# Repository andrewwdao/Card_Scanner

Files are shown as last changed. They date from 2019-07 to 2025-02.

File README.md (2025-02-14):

# Attendance Checking System for students of Can Tho University



 <!-- [![License](https://img.shields.io/github/license/minhan74/Card_Scanner.svg)](LICENSE) -->


## Download

```bash
git clone --recursive https://github.com/minhan74/Card_Scanner.git
git submodule update --init --recursive
```

## Documentation

This project aims to create a portable device that is used to check student attendance based on their student ID card.

* **[Full Report]**: detailed explaination on how we create this system and how to use it (school scientific research report - in Vietnamese).
* **[Hardware assembling instruction]**: how to re-create the hardware (extracted from the full report - in Vietnamese).
* **[Hardware files]**: ready-to-print parts of the cover and PCB.
* **[ESP32 - How to use the device]**: Guidance on how to properly setup the device for usage (extracted from the full report - in Vietnamese).
* **[ESP32 - Flash Instruction]**: Instruction on how to flash a ready-to-use binary file to esp32 (in English).
* **[ESP32 - Prepare Developing Environment]**: Guidance on how to prepare an appropriate developing environment for esp32 (in English).
* **[Web server - How to use]**: How to use the web server (in Vietnamese).
* **[Web server - Create localhost server]**: How to create a localhost server for locally use (in Vietnamese).
* **[Web server - Create globalhost server]**: How to create a globalhost server for internet use (in Vietnamese).

This project includes two main components:

* A Card Reader Device
* A Web Server

## Card Reader Device

This device is designed for reading student card, indicates student information and save these information into SD card. The device can connect to a server (locally or globally) to manipulate student's attendance information.

### Hardware

#### PCB

Designed in Altium 18.

Manufactured in china.

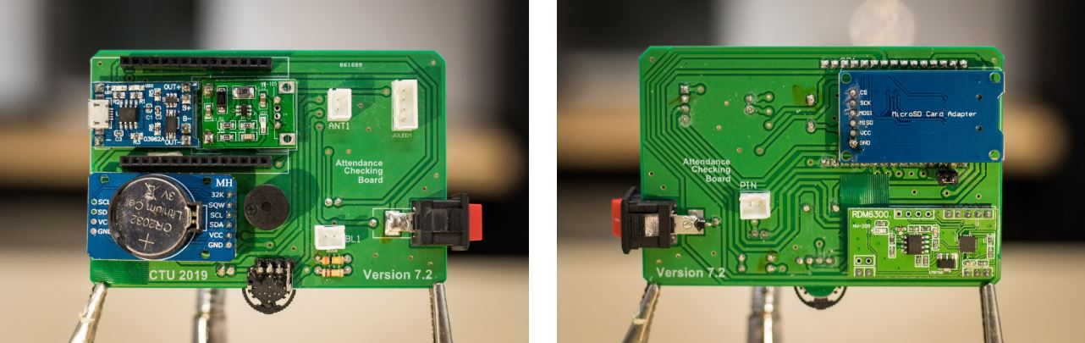
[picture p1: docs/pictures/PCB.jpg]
pcb


#### Cover

Designed using Fusion360.

Created by 3D printing and laser cutting.

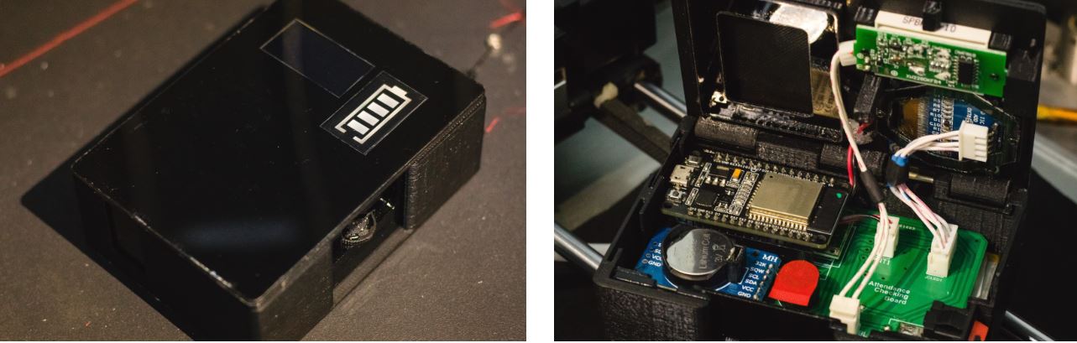
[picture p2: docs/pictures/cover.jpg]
cover


### Embedded software

Microcontroller: ESP32 DEV KIT V1

Peripherals: RDM6300 RFID reader, RTC module, SD card reader, 3-state button, voltage converter, lipo battery, lipo charger.

Run on both core of an ESP32 using FreeRTOS. Compiled by ESP-IDF with Arduino core as a component.

* ESP-IDF version: 3.2
* Compiler version: 5.2.0
* Arduino components version: 1.0.2

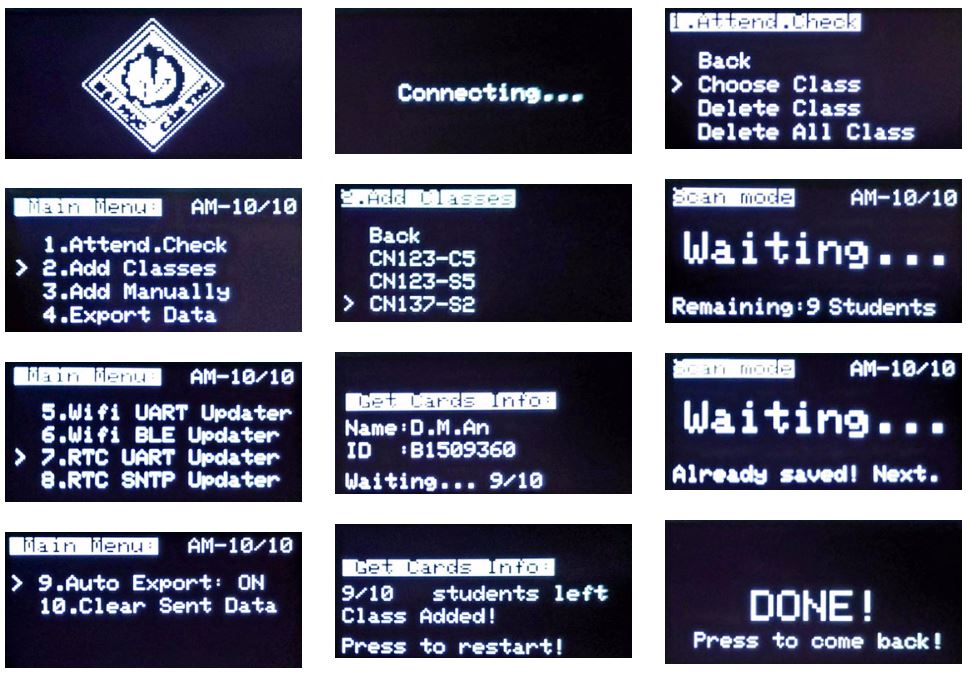
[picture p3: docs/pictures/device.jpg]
device


## Web Server

Written in PHP 7.3.18

Based on:

* Xampp v7.3.18
* Lavarel framework 5.6.22

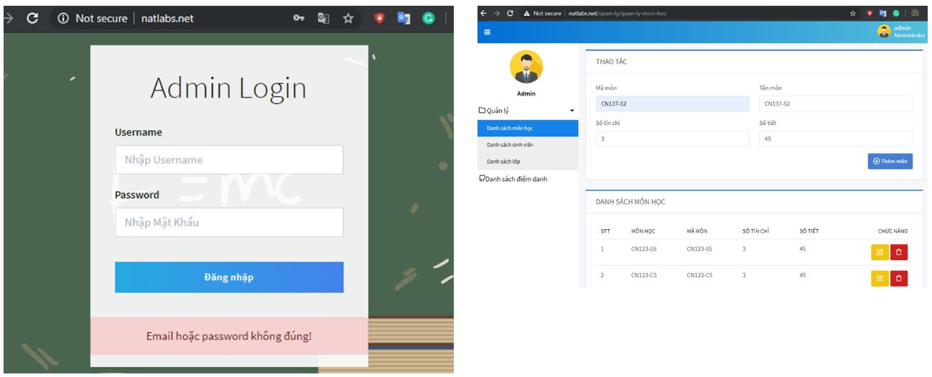
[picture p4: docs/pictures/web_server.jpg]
web_server


## Sponsor by

* Msc. Khac-Nguyen Nguyen, Can Tho University. <nknguyen@ctu.edu.vn>
* Can Tho University school scientific research fund.

## Supervised by

* Assoc. Prof. Chi-Ngon Nguyen, Can Tho University. <ncngon@ctu.edu.vn>
* Dr. Chanh-Nghiem Nguyen, Can Tho University. <ncnghiem@ctu.edu.vn>
* Msc. Khac-Nguyen Nguyen, Can Tho University. <nknguyen@ctu.edu.vn>

## Credited

* Mr. Quang-Thong Duong-Pham was responsible for PCB design, product testing and reporting.
* Mr. Quang-Nhut Tran was responsible for web server development.
* Mr. Anh-Khoi Tran was responsible for database and web server improving.
* Mr. Minh-An Dao was responsible for embedded software development.

 (c) 2019 Quang-Thong Duong-Pham <baronvn7197@gmail.com> - Quang-Nhut Tran <nhut1202@gmail.com> - Anh-Khoi Tran <khoitrananh.20@gmail.com> - Minh-An Dao <darns.smiths.9f@icloud.com> - Can Tho University.

<!-- Links -->
[Full Report]:https://bit.ly/card_scanner
[Hardware assembling instruction]:/docs/[Hardware]How_to_assemble.pdf
[Hardware files]: /hardware/
[ESP32 - How to use the device]:/docs/[ESP32]How_to_use_device.pdf
[ESP32 - Flash Instruction]: /docs/[ESP32]flash_ready-to-use_binary.md
[ESP32 - Prepare Developing Environment]: /docs/[ESP32]prepare_developing_environment.md
[Web server - How to use]: /docs/[Web_server]How_to_use_web_server.md
[Web server - Create localhost server]: /docs/[Web_server]Create_localhost_server.md
[Web server - Create globalhost server]:[Web_server]Create_globalhost_server.md

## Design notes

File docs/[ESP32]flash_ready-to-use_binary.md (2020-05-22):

# FLASH READY-TO-USE ESP32 BINARY (IN WINDOWS)

## Step 0: download [esptool]

You can skip this step if you already install the developing environment

## Step 1: Open mingw32.exe (if developing env is installed) or cmd (if install only esptool)

- Locate to the project folder (/esp32), you should see the file _CARD-SCANNER.bin_
- Plug in your esp32, determine the port name (COM5, COM14, ...)
- Download the binary file to the esp32:

```bash
python /<esptool directory>/esptool.py --chip esp32 --port COM14 --baud 921600 --before default_reset --after hard_reset write_flash -z --flash_mode dio --flash_freq 40m --flash_size detect 0x10000 /<project_directory>/CARD-SCANNER.bin
```

- Change the directory to your appropriate situation. Successfully uploaded program will look something like this:

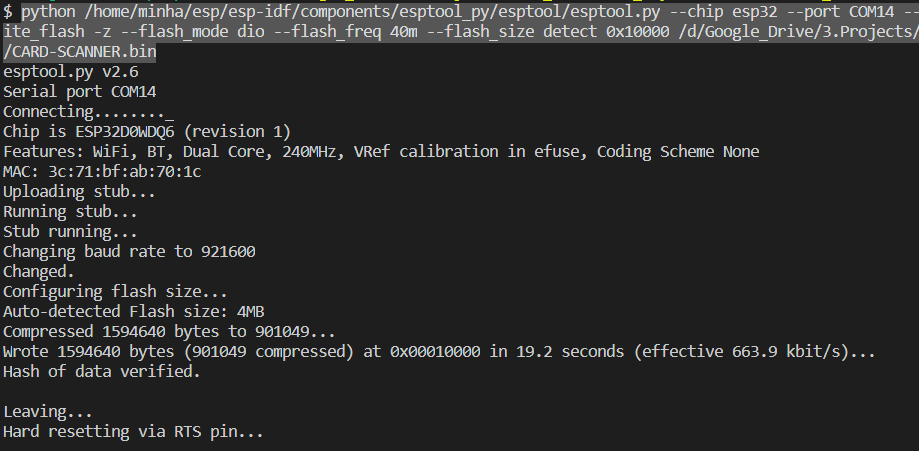
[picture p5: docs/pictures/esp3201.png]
esp3201
  

[esptool]: https://github.com/espressif/esptool

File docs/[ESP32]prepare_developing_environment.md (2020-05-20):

# PREPARE ESP-IDF PROGRAMMING ENVIRONMENT FOR ESP32

## Step 1: Download the environment – MSYS32

- Go to: <https://dl.espressif.com/dl/esp32_win32_msys2_environment_and_gcc8_toolchain-20191220.zip>
- Download the latest Windows all-in-one toolchain & MSYS2 zip file (~600mb)
- UNRAR the zip file in C:/
- Done setting up the pre-built environment.

## Step 2: Setting up the ESP-IDF framework

- Open mingw32.exe and start typing:

```bash
mkdir -p ~/esp
cd ~/esp
git clone --recursive https://github.com/espressif/esp-idf.git
```

- Add IDF_PATH to user profile:
  - Open the export_idf_path.sh in the crucial_files folder (within this folder) and fix the user to your user, then copy it to the directory: C:\msys32\etc\profile.d
  - Close MSYS2 window and reopen it and enter: printenv IDF_PATH to check the path
- Configure ESP-IDF to a useable version (old version, you can try to upgrade it later):

```bash
cd $IDF_PATH
git fetch
git checkout release/v3.2
git pull
git submodule update --init --recursive
python --version
python -m pip install --user -r $IDF_PATH/requirements.txt
```

## Step 3: Set up Arduino as a component in ESP-IDF

- Go to project folder, and type in

```bash
cd workspace/components/arduino
git checkout 1.0.2
git submodule update --init --recursive
```

- Replace _cc.h_ from crucial_files folder into _cc.h_ in:

```bash
C:\msys32\home\minha\esp\esp-idf\components\lwip\lwip\test\unit\esp\arch
```

This cc.h has been changed from:

```C
#include "ports/unix/port/include/arch/cc.h"
```

To

```C
#include "lwip/port/esp32/include/arch/cc.h"
```

## Step 4: open MSYS2 (mingw32.exe) and move to project folder (/esp32/workspace/)

- Try to compile source code with

```bash
make clean
make -j4 app
```

- Final message should be like this:

esp3202

- If the above message appears, then congratulation, you are properly set up esp-idf environment for this project.
- However, this environment is out dated. If you need to upgrade to the latest release, please make backup where needed since it will need a lot of careful modification to successfully compile with newer version.

**You can now use VScode or your favorite text editor to edit the code.**

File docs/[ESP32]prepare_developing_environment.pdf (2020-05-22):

# PREPARE ESP-IDF PROGRAMMING ENVIRONMENT FOR ESP32

## Step 1: Download the environment – MSYS32

Go to: https://dl.espressif.com/dl/esp32_win32_msys2_environment_and_gcc8_toolchain-20191220.zip Download the latest Windows all-in-one toolchain & MSYS2 zip file (~600mb)
UNRAR the zip file in C:/
Done setting up the pre-built environment.

## Step 2: Setting up the ESP-IDF framework

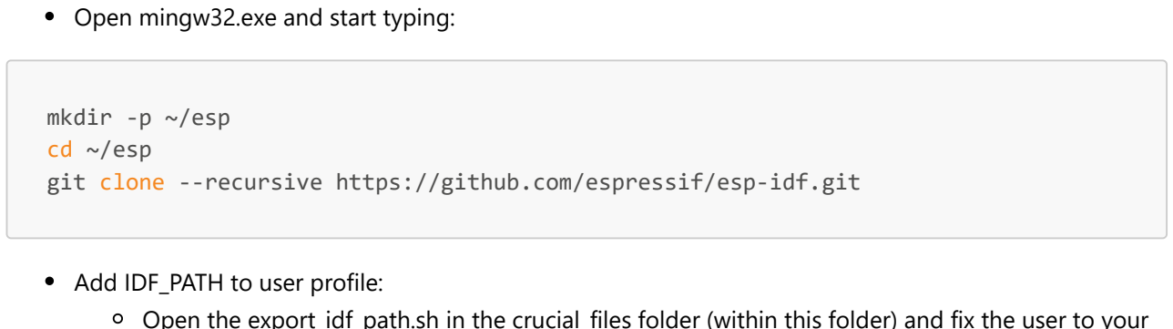
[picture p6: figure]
Open mingw32.exe and start typing:; mkdir -p ~/esp cd ~/esp git clone --recursive https://github.com/espressif/esp-idf.git; Add IDF_PATH to user profile:

Open the export_idf_path.sh in the crucial_files folder (within this folder) and fix the user to your user, then copy it to the directory: C:\msys32\etc\profile.d
Close MSYS2 window and reopen it and enter: printenv IDF_PATH to check the path
Configure ESP-IDF to a useable version (old version, you can try to upgrade it later):

cd $IDF_PATH
git fetch
git checkout release/v3.2
git pull
git submodule update --init --recursive
python --version
python -m pip install --user -r $IDF_PATH/requirements.txt

## Step 3: Set up Arduino as a component in ESP-IDF

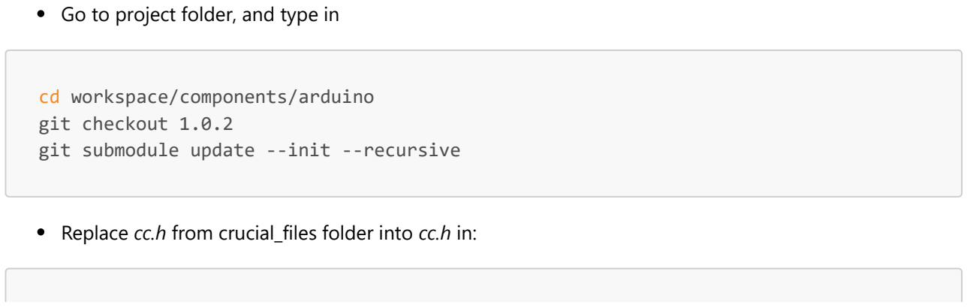
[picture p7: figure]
Go to project folder, and type in; cd workspace/components/arduino git checkout 1.0.2 git submodule update --init --recursive

Replace cc.h from crucial_files folder into cc.h in:

C:\msys32\home\minha\esp\esp-idf\components\lwip\lwip\test\unit\esp\arch

This cc.h has been changed from:

#include "ports/unix/port/include/arch/cc.h"

To

#include "lwip/port/esp32/include/arch/cc.h"

## Step 4: open MSYS2 (mingw32.exe) and move to project folder (/esp32/workspace/)

Try to compile source code with

make clean
make -j4 app

Final message should be like this:

If the above message appears, then congratulation, you are properly set up esp-idf environment for this project.
However, this environment is out dated. If you need to upgrade to the latest release, please make backup where needed since it will need a lot of careful modification to successfully compile with newer version.

You can now use VScode or your favorite text editor to edit the code.

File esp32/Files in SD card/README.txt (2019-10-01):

***Follow this instruction to properly use the Attendance Checking Device

Folder:
- Await:  this folder will store data files that haven't transfer to the server
- Sent:   this folder will store data files that have been transfer successfully to the server
- Import: this folder will help you import data manually to the system (see README.txt inside this folder)

This content is created by CTU students
(c) 2019 - An Minh Dao - Nhut Quang Tran - Thong Pham Quang Duong

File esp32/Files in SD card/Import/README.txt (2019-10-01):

*Copy your files to this folder to manually import data to the System
***Instruction: 

*Step 1:
First, save the class name into the file "classes.txt" in this folder.
For example, you want to import class CN123-S6.
 - Open "classes.txt"
 - Add: CN123-S6 to a new line
 - Press enter to confirm
 - Save the file and exit

*Step 2:
Prepare your class file as followed:
 - Class file name: 
CN123-S6.txt
 - Content:
B1509360|Dao Minh An
B1509361|Pham Hoang Anh
B1509397|Tran Quang Nhut
B1509399|Le Vo Thanh Phong
B1509482|Duong Pham Quang Thong

 - Press enter to confirm
 - Save the file to this folder

*Step 3:
Eject the SD card, put it on the Device, choose Import Manually

Enjoy.

This content is created by CTU students
(c) 2019 - An Minh Dao - Nhut Quang Tran - Thong Pham Quang Duong

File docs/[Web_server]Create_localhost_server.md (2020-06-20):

# HƯỚNG DẪN TẠO SERVER LOCAL

- Để chạy localhost, ta cần cài đặt:

[Xampp v7.3.18 x64](https://www.apachefriends.org/xampp-files/7.3.18/xampp-windows-x64-7.3.18-0-VC15-installer.exe)
[Xampp v7.3.2 x32](https://sourceforge.net/projects/xampp/files/XAMPP%20Windows/7.3.2/xampp-portable-win32-7.3.2-0-VC15-installer.exe/download)

- **Bước 0:** Đưa php vào system path:

  - Nhấn phím windows, nhập “path” để tìm Edit the system environment variable:

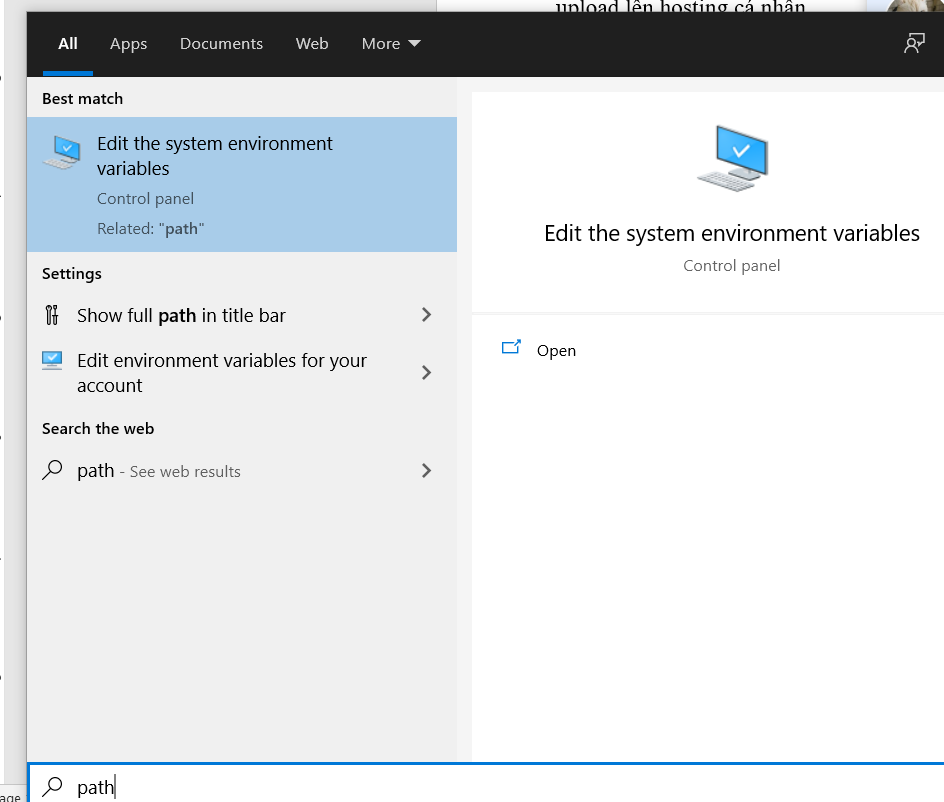
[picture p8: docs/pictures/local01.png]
local01
  

  - Chọn Environment Variables:

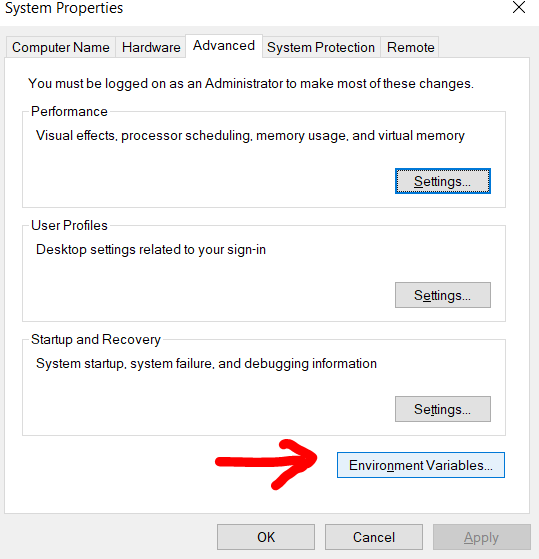
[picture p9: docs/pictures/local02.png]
local02
  

  - Chọn path > Edit:

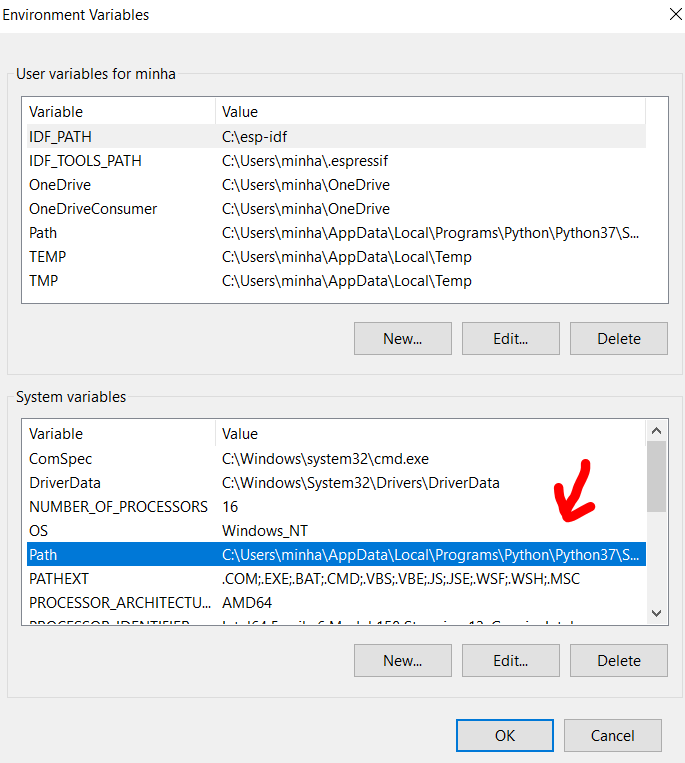
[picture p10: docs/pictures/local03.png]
local03
  

  - Chọn New, điền vào C:\xampp\php

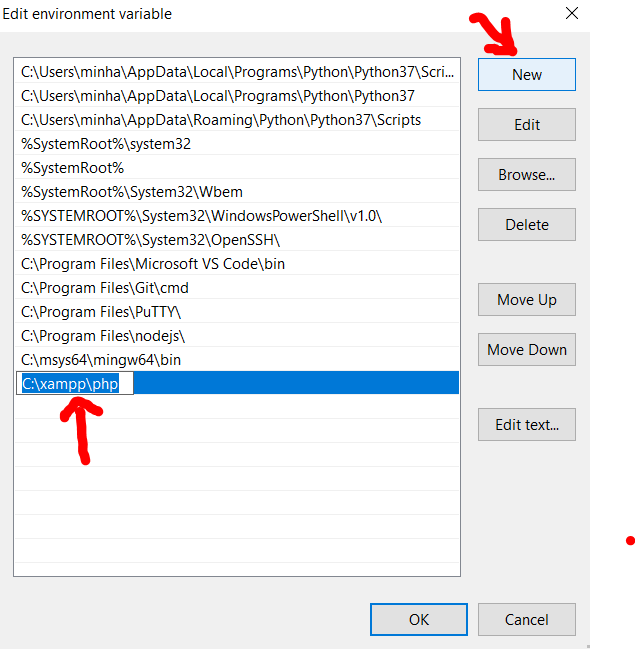
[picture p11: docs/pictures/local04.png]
local04
  

  - Chọn OK để save lại.

- **Bước 1:** Giải nén file card_scanner.zip(\web_server\local\) và chép thư mục card_scanner vào thư mục C:\xampp\htdocs.
- **Bước 2:** Khởi động phần mềm Xampp để tạo môi trường cho Localhost. Nhấn Start cho Apache và MySQL.

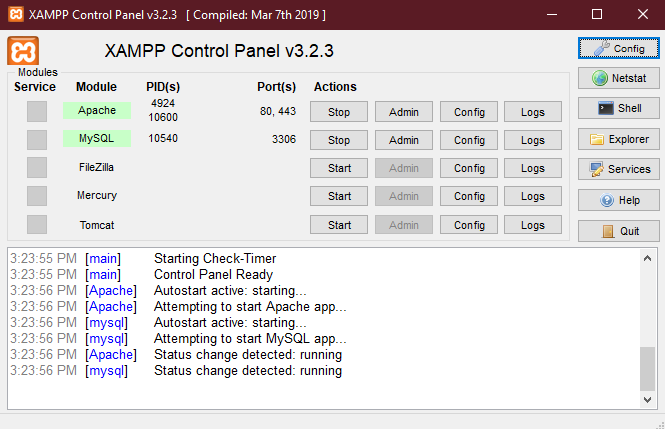
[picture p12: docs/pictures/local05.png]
local05


- **Bước 3:** truy cập <http://localhost/phpmyadmin> để vào trang quản lý Database.
  - Tạo new database với tên countstd:

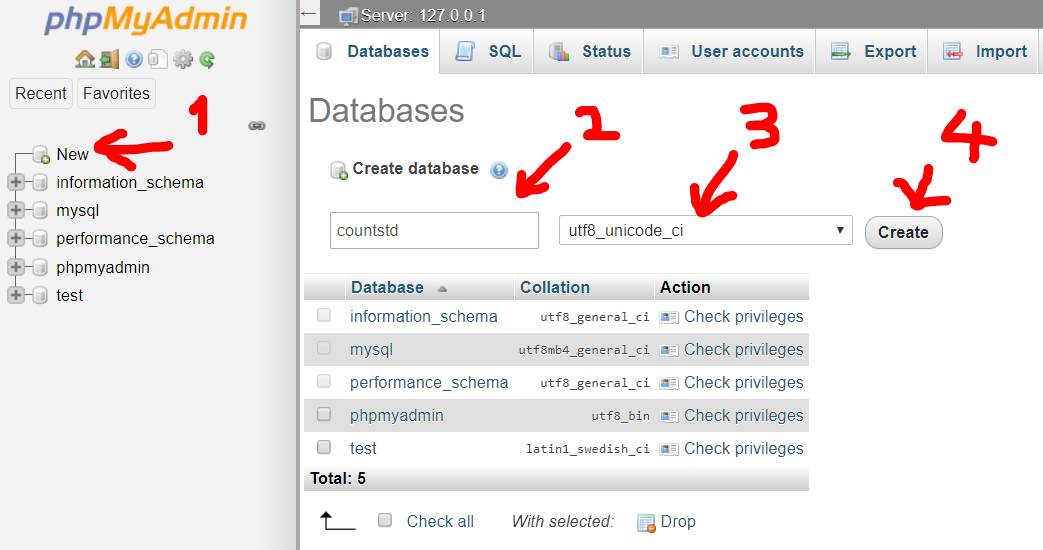
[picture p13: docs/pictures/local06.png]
local06
  

  - Import database có sẵn vào database vừa được tạo, chọn import:

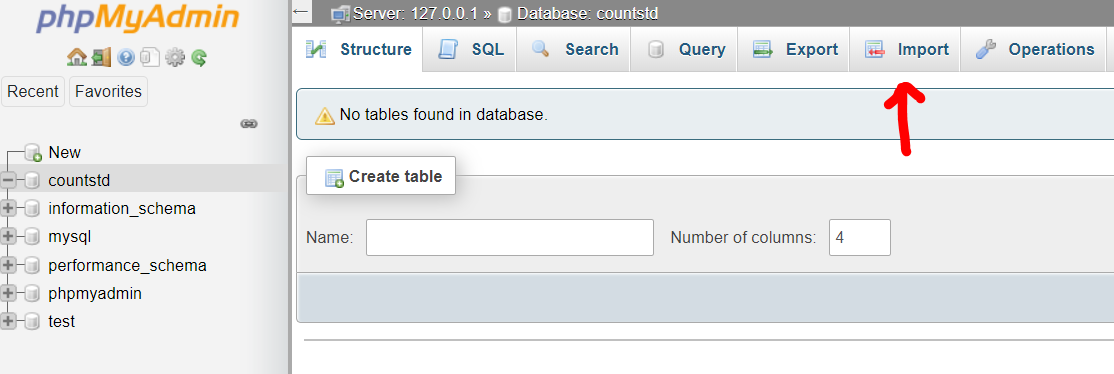
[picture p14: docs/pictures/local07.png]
local07
  

  - Chọn Choose file và chọn vào file countstd.sql (\web_server\local\) > Bấm Go ở cuối trang

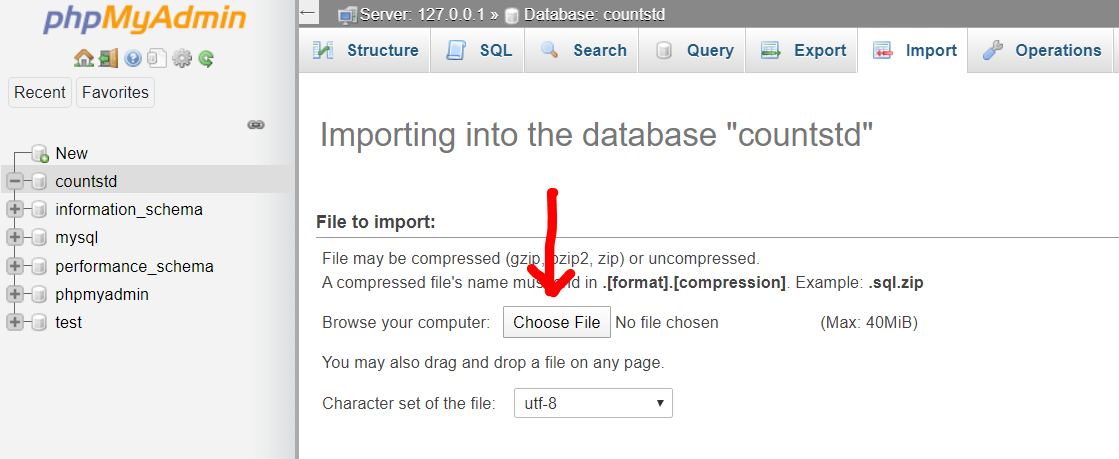
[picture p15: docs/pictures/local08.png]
local08
  

- **Bước 4:** Mặc định, hệ thống đã có tài khoản admin. Nếu muốn thay đổi tài khoản admin, xóa admin cũ trong bảng admin từ database countstd trong phpMyAdmin, sau đó truy cập vào tệp tin _DatabaseSeeder.php_ theo đường dẫn C:\xampp\htdocs\card_scanner\database\seeds. Thay đổi thông tin tài khoản đăng nhập mong muốn:

```python
class seedAdmin extends Seeder
{
    public function run()
    {
        DB::table('admin')->insert([
            ['taikhoan' => 'tên đăng nhập ở đây', 'password' => bcrypt('Mật khẩu ở đây')],
            ['taikhoan' => 'admin', 'password' => bcrypt('123456')],
        ]);
    }
}
```

- **Bước 5:** Mở cmd, gõ vào:

```bash
cd C:\xampp\htdocs\card_scanner
```

- **Bước 6:** Thực thi thay đổi cơ sở dữ liệu (LƯU Ý: nếu gặp lỗi, thì kiểm tra lại bảng admin từ database và đảm bảo không có tài khoản admin bị trùng):

```bash
php artisan db:seed
```

- **Bước 7:** Tiến hành chạy server:

```bash
php artisan serve --port=2020
```

local09

- **Bước 8:** Truy cập _<http://localhost:2020>_ hoặc nhấp đúp vào shortcut _Card Scanner Web Server_ (C:\xampp\htdocs\card_scanner) để truy cập hệ thống.

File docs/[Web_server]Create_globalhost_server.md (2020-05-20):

# HƯỚNG DẪN UPLOAD SOURCE CODE LÊN HOSTING CÁ NHÂN

- Hiện tại mã nguồn của hệ thống quản lý điểm danh đang được quản lý dưới tên tài khoản mặc định được tạo sẵn như sau:
  - Username: admin
  - Password: 123456
- Để bắt đầu upload source code lên hosting cá nhân trước hết phải đảm bảo người dùng đã có đủ 2 yếu tố là:
  - Hosting: là máy chủ sẽ chứa toàn bộ mã nguồn và đảm bảo đáp ứng kết nối từ phía người dùng. Ở hướng dẫn này sẽ dử dụng hosting là hawkhost.com. Đối với hosting cần có MySQL Databases.
  - Domain: là tên miền cho phép truy cập vào hệ thống máy chủ. Tên miền sử dụng trong hướng dẫn này là www.natlabs.net
- Khi đã có đủ các điều kiện cần thiết ta sẽ tiến hành upload theo các bước sau:
  - Đăng nhập vào cPanel của hosting bằng cách nhập url vào trình duyệt web với cú pháp: www.“your-domain”/cpanel. (VD: www.natlabs.net/cpanel )
  - Trình duyệt sẽ điều hướng đến trang đăng nhập như sau:

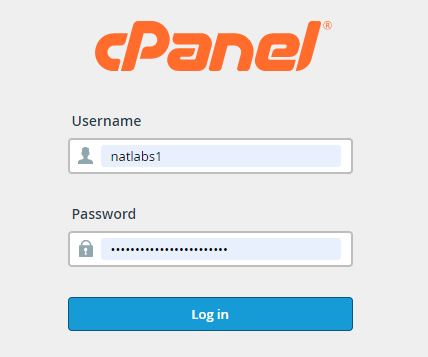
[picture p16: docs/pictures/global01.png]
Global01
  

  - Sau khi đăng nhập thành công ta chọn File Manager để truy cập vào trình quản lý tệp tin của máy chủ như sau:
  
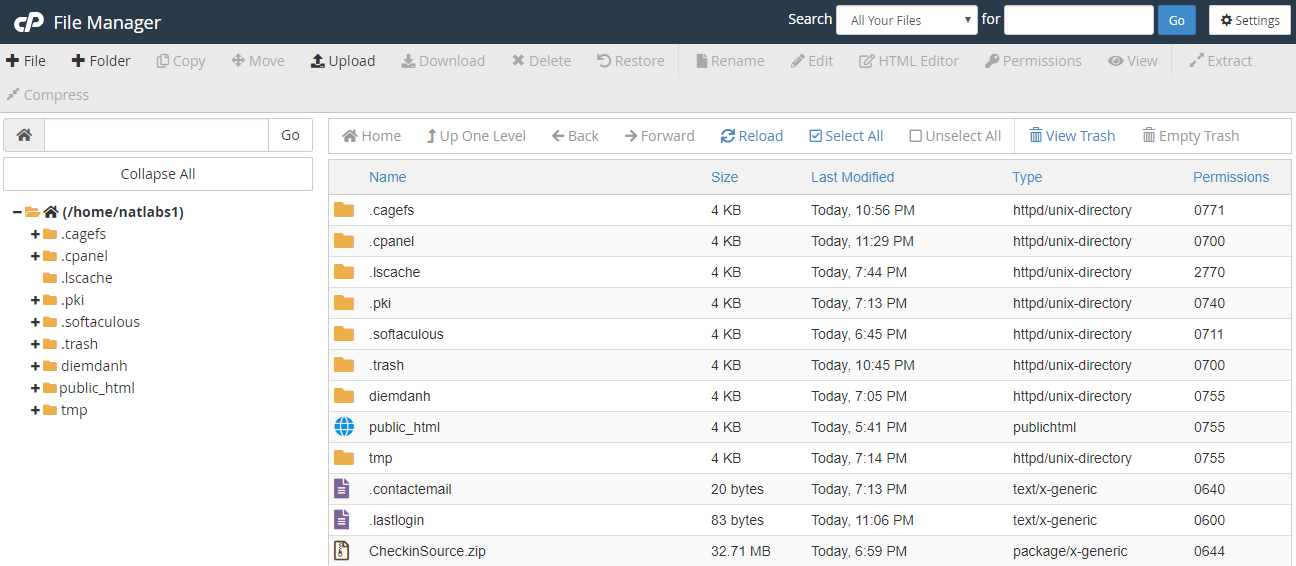
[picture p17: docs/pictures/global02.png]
Global02
  

  - Ở giao diện File Manager ta nhấp chuột chọn nút Upload trên thanh công cụ, sau đó nhấp chọn nút Upload File và trỏ đến thư mục chưa tệp tin CheckinSource.zip (\web_server\global\) và bấm Open. Sau đó chờ tệp tin được upload thành công vào hệ thống.
  - Quay lại giao diện File Manager nhấp chuột phải vào tệp tin CheckinSource.zip chọn Extract và chờ đến khi tệp tin được xả nén thành công. Ta sẽ thấy lúc này sẽ xuất hiện 2 thư mục mới có tên là “card_scanner” và “publish_html”.
  
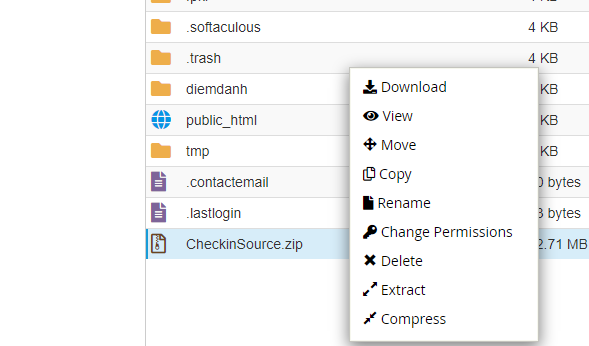
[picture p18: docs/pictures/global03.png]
Global03
  

  - Như vậy là đã thành công upload sources code lên hệ thống cPanel của hosting.
- Quay lại giao diện chính của cPanel chọn MySQL Databases trong mục Database. Trình duyệt sẽ điều hướng đến trang quản lý cơ sở dữ liệu.
  - Ta tạo 1 cơ sở dữ liệu mới tên “countstd” như hình và nhấp chuột vào nút Create Database.
  
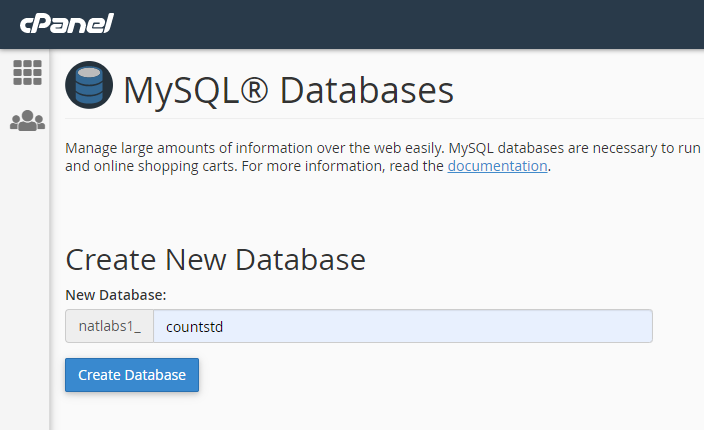
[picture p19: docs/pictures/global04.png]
Global04
  

  - Tiếp tục tạo User Database như hình bên dưới và nhấp nút Create User
  
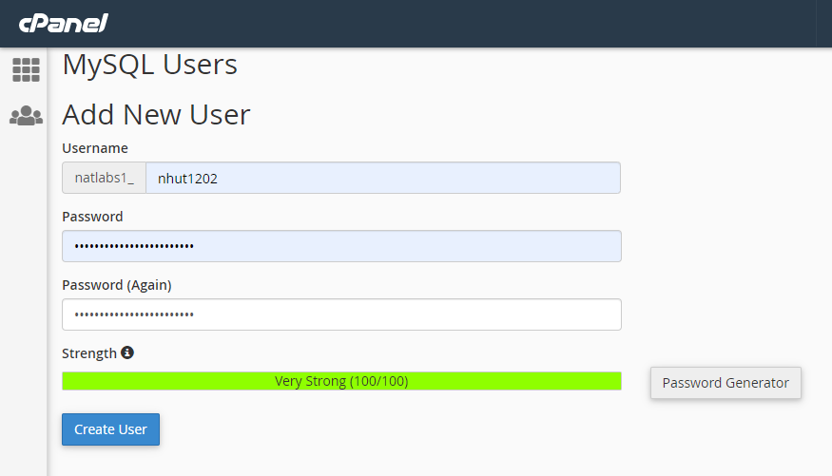
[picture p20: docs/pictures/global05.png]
Global05
  

  - Tiếp tục là liên kết User vừa tạo với Database đã tạo ở trên bằng cách chọn và nhấp chuột vào nút Add như hình:
  
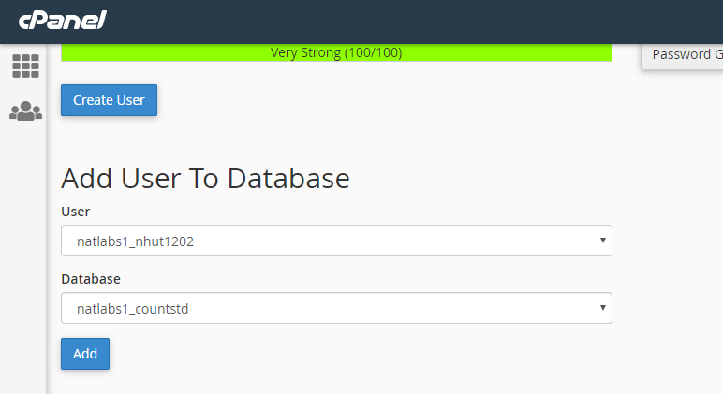
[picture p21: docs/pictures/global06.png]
Global06
  

- Sau khi đã hoàn tất các bước tạo cơ sở dữ liệu, ta quay lại giao diện File Manager nhấp chuột truy cập vào thư mục “card_scanner”.
  - Nhấp chọn nút Setting ở góc trên bên trái của giao diện File Manager. Trong hộp thoại “Freferences”, tích chọn Show Hidden File sau đó nhấp chọn Save để lưu và đóng hộp thoại.
  
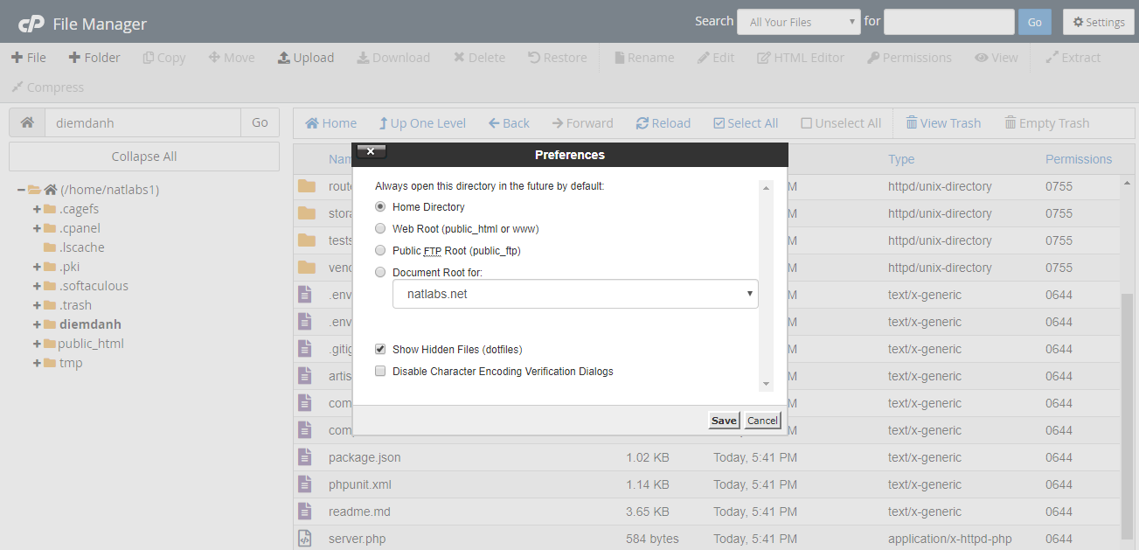
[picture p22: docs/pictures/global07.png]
Global07
  

  - Trong thư mục “card_scanner” ta nhấp chọn chuột phải vào tệp tin .env và chọn Edit
  
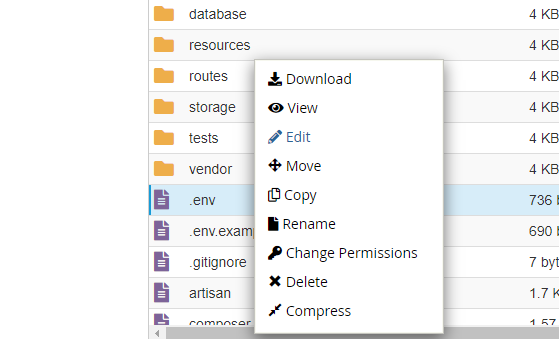
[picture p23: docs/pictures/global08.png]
Global08
  

  - Trong trang Edit tệp tin .env ta sửa lại các thông số liên quan đến Database ở dòng 12, 13, 14 lần lượt là Tên DB, User và Password vừa tạo ở trên. Sau đó nhấp chọn nút Save Change để lưu thay đổi.
  
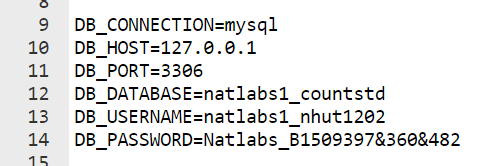
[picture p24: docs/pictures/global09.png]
Global09
  

- Quay lại giao diện chính của cPanel chọn mục phpMyAdmin.
  - Trong giao diện phpMyAdmin chọn tên Database đã tạo ở danh sách DB phía bên trái, sau đó nhấp chọn nút Insert. Trong mục File to import nhấp chọn nút Choose File và trỏ đến file “countstd.sql” trên máy tính và nhấp chọn Open.
  
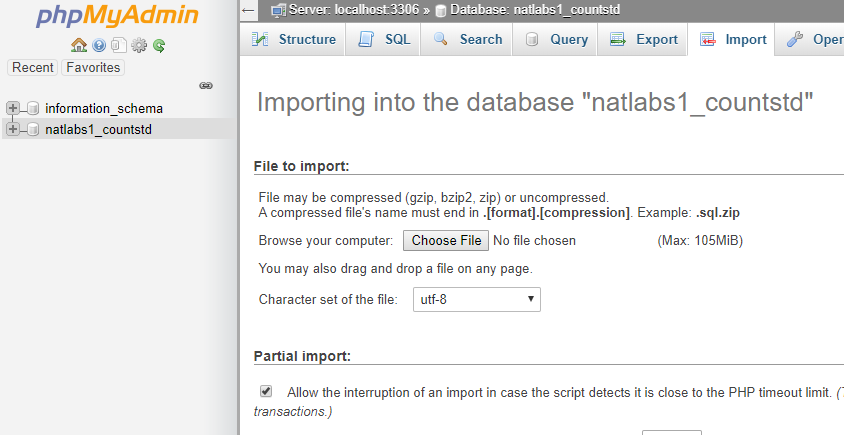
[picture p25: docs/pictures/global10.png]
Global10
  

  - Lăn cuộn chuột đến cuối trang và nhấp chọn nút Go để import cơ sở dữ liệu vào MySQL.
- Lúc này ta truy cập vào Domain đã đăng ký để truy cập vào trang đăng nhập của hệ thống điểm danh với tài khoản mặc định ở trên.
- Vậy là ta đã hoàn thành việc publish source code của hệ thống điểm danh lên hosting cá nhân thành công. Hệ thống server điểm danh đã sẵn sàng để sử dụng.

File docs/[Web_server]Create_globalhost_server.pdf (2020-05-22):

# HƯỚNG DẪN UPLOAD SOURCE CODE LÊN HOSTING CÁ NHÂN

Hiện tại mã nguồn của hệ thống quản lý điểm danh đang được quản lý dưới tên tài khoản mặc định được tạo sẵn như sau:

Username: admin
Password: 123456

Để bắt đầu upload source code lên hosting cá nhân trước hết phải đảm bảo người dùng đã có đủ 2 yếu tố là:

Hosting: là máy chủ sẽ chứa toàn bộ mã nguồn và đảm bảo đáp ứng kết nối từ phía người dùng. Ở hướng dẫn này sẽ dử dụng hosting là hawkhost.com. Đối với hosting cần có MySQL Databases.
Domain: là tên miền cho phép truy cập vào hệ thống máy chủ. Tên miền sử dụng trong hướng dẫn này là www.natlabs.net

Khi đã có đủ các điều kiện cần thiết ta sẽ tiến hành upload theo các bước sau:

Đăng nhập vào cPanel của hosting bằng cách nhập url vào trình duyệt web với cú pháp: www.“your-domain”/cpanel. (VD: www.natlabs.net/cpanel )
Trình duyệt sẽ điều hướng đến trang đăng nhập như sau:

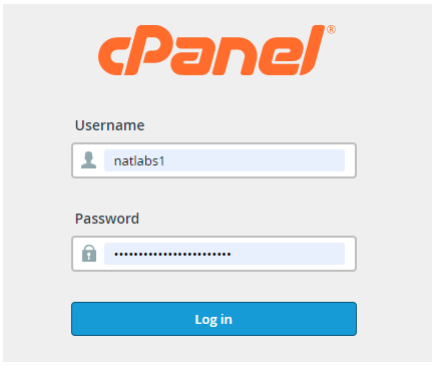
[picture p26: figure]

Sau khi đăng nhập thành công ta chọn File Manager để truy cập vào trình quản lý tệp tin của máy chủ như sau:


Ở giao diện File Manager ta nhấp chuột chọn nút Upload trên thanh công cụ, sau đó nhấp chọn nút Upload File và trỏ đến thư mục chưa tệp tin CheckinSource.zip (\web_server\global) và bấm Open. Sau đó chờ tệp tin được upload thành công vào hệ thống.
Quay lại giao diện File Manager nhấp chuột phải vào tệp tin CheckinSource.zip chọn Extract và chờ đến khi tệp tin được xả nén thành công. Ta sẽ thấy lúc này sẽ xuất hiện 2 thư mục mới có tên là “card_scanner” và “publish_html”.

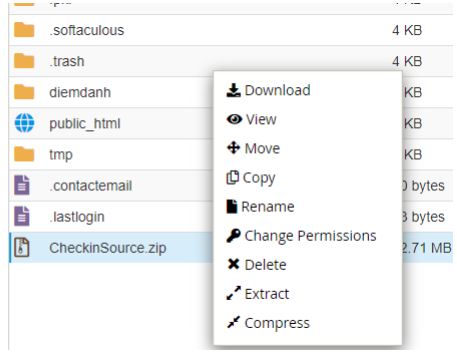
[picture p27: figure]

Như vậy là đã thành công upload sources code lên hệ thống cPanel của hosting.

Quay lại giao diện chính của cPanel chọn MySQL Databases trong mục Database. Trình duyệt sẽ điều hướng đến trang quản lý cơ sở dữ liệu.

Ta tạo 1 cơ sở dữ liệu mới tên “countstd” như hình và nhấp chuột vào nút Create Database.

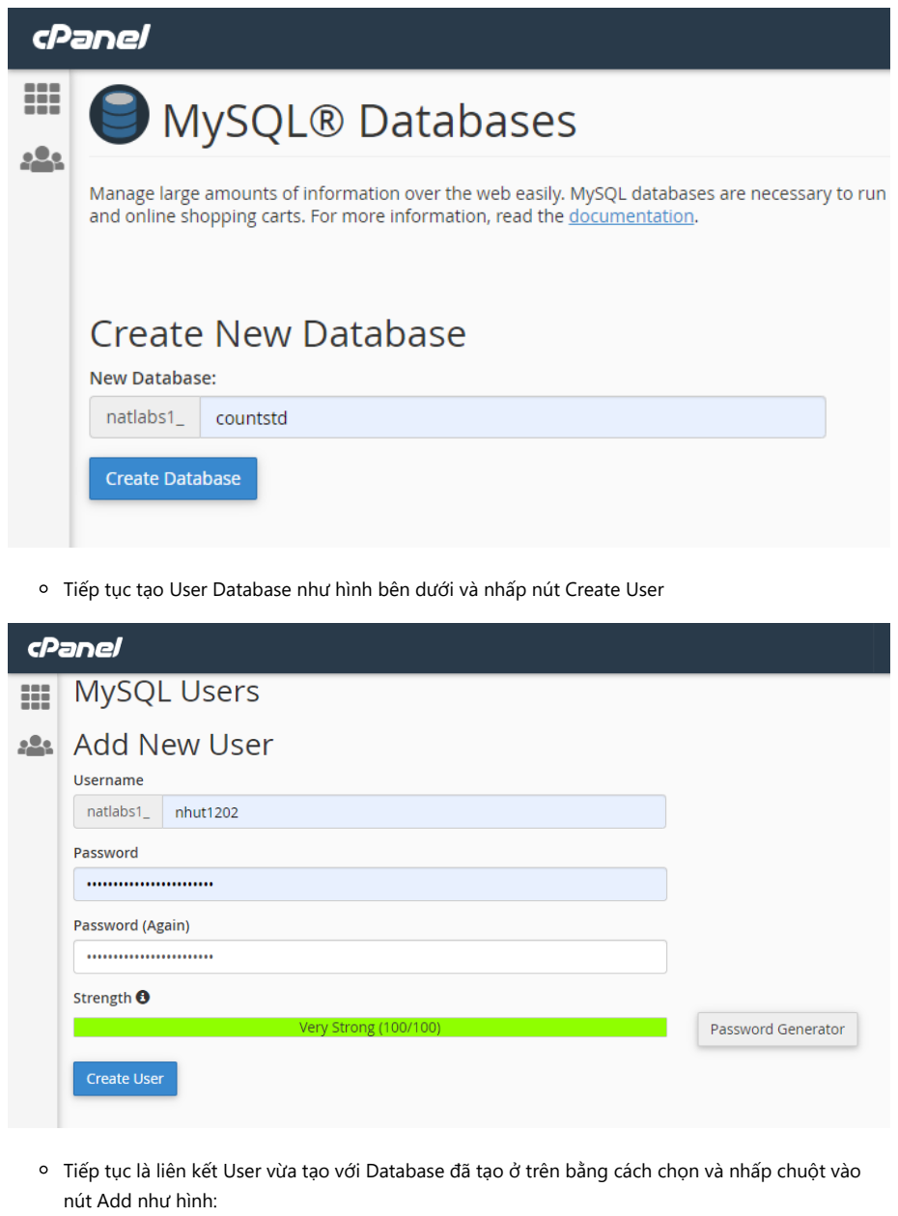
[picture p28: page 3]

Tiếp tục tạo User Database như hình bên dưới và nhấp nút Create User

Tiếp tục là liên kết User vừa tạo với Database đã tạo ở trên bằng cách chọn và nhấp chuột vào nút Add như hình:


Sau khi đã hoàn tất các bước tạo cơ sở dữ liệu, ta quay lại giao diện File Manager nhấp chuột truy cập vào thư mục “card_scanner”.

Nhấp chọn nút Setting ở góc trên bên trái của giao diện File Manager. Trong hộp thoại “Freferences”, tích chọn Show Hidden File sau đó nhấp chọn Save để lưu và đóng hộp thoại.

Trong thư mục “card_scanner” ta nhấp chọn chuột phải vào tệp tin .env và chọn Edit


Trong trang Edit tệp tin .env ta sửa lại các thông số liên quan đến Database ở dòng 12, 13, 14 lần lượt là Tên DB, User và Password vừa tạo ở trên. Sau đó nhấp chọn nút Save Change để lưu thay đổi.

Quay lại giao diện chính của cPanel chọn mục phpMyAdmin.

Trong giao diện phpMyAdmin chọn tên Database đã tạo ở danh sách DB phía bên trái, sau đó nhấp chọn nút Insert. Trong mục File to import nhấp chọn nút Choose File và trỏ đến file “countstd.sql” trên máy tính và nhấp chọn Open.

với tài khoản mặc định ở trên.

Lăn cuộn chuột đến cuối trang và nhấp chọn nút Go để import cơ sở dữ liệu vào MySQL.

Lúc này ta truy cập vào Domain đã đăng ký để truy cập vào trang đăng nhập của hệ thống điểm danh

Vậy là ta đã hoàn thành việc publish source code của hệ thống điểm danh lên hosting cá nhân thành công. Hệ thống server điểm danh đã sẵn sàng để sử dụng.

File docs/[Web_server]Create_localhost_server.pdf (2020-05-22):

# HƯỚNG DẪN TẠO SERVER LOCAL

Để chạy localhost, ta cần cài đặt:

Xampp v7.3.18 (https://www.apachefriends.org/xampp-files/7.3.18/xampp-windows-x64-7.3.18-0-VC15-installer.exe)

Bước 0: Đưa php vào system path:

Nhấn phím windows, nhập “path” để tìm Edit the system environment variable:


Chọn Environment Variables:


Chọn path > Edit:


Chọn New, điền vào C:\xampp\php


Chọn OK để save lại.

Bước 1: Giải nén file card_scanner.zip(\web_server\local) và chép thư mục card_scanner vào thư mục C:\xampp\htdocs.

Bước 2: Khởi động phần mềm Xampp để tạo môi trường cho Localhost. Nhấn Start cho Apache và MySQL.


Bước 3: truy cập http://localhost/phpmyadmin để vào trang quản lý Database.

Tạo new database với tên countstd:

Import database có sẵn vào database vừa được tạo, chọn import:


Chọn Choose file và chọn vào file countstd.sql (\web_server\local) > Bấm Go ở cuối trang

Bước 4: Mặc định, hệ thống đã có tài khoản admin. Nếu muốn thay đổi tài khoản admin, xóa admin cũ trong bảng admin từ database countstd trong phpMyAdmin, sau đó truy cập vào tệp tin DatabaseSeeder.php theo đường dẫn C:\xampp\htdocs\card_scanner\database\seeds. Thay đổi thông tin tài khoản đăng nhập mong muốn:

class seedAdmin extends Seeder
{
public function run()
{
DB::table('admin')->insert([
['taikhoan' => 'tên đăng nhập ở đây', 'password' => bcrypt('Mật khẩu ở đây')],
['taikhoan' => 'admin', 'password' => bcrypt('123456')],
]);
}
}

Bước 5: Mở cmd, gõ vào:

cd C:\xampp\htdocs\card_scanner


Bước 6: Thực thi thay đổi cơ sở dữ liệu (LƯU Ý: nếu gặp lỗi, thì kiểm tra lại bảng admin từ database và
đảm bảo không có tài khoản admin bị trùng):

php artisan db:seed

Bước 7: Tiến hành chạy server:

php artisan serve --port=8000

Bước 8: Truy cập http://localhost:8000 để truy cập hệ thống

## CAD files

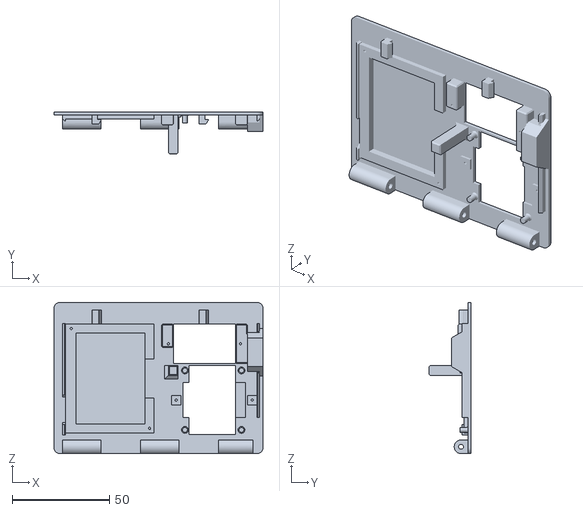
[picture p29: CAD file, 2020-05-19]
hardware/3D Files/1.Top.stl
107.2 x 21.3 x 77.6

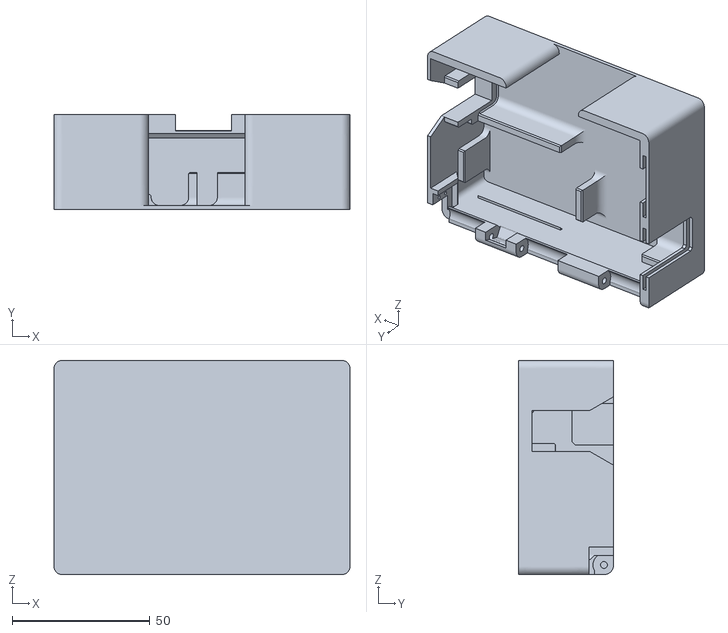
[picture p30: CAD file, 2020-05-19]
hardware/3D Files/2.Bottom.stl
107.2 x 34.5 x 77.6

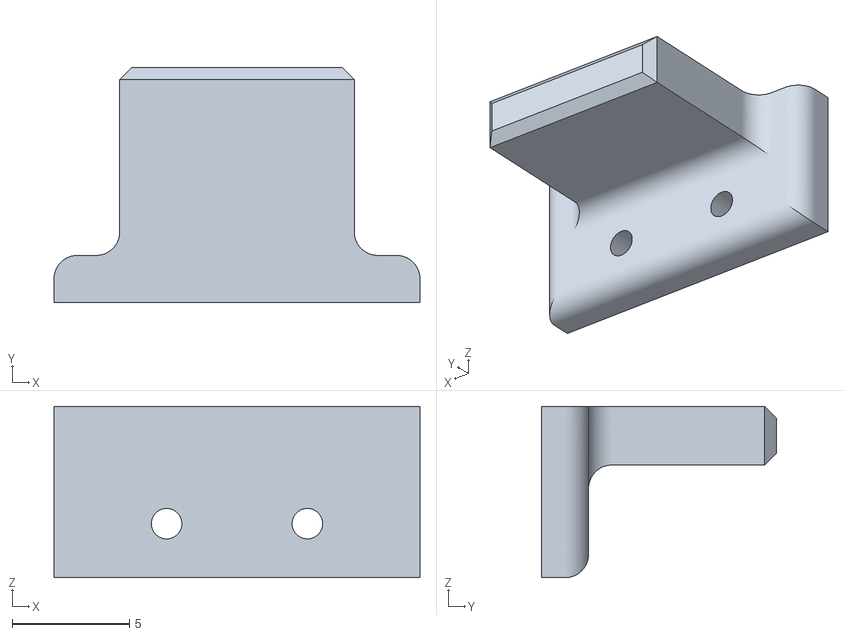
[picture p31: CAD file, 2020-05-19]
hardware/3D Files/2.Bottom_Support_PCB.stl
15.6 x 10.0 x 7.30

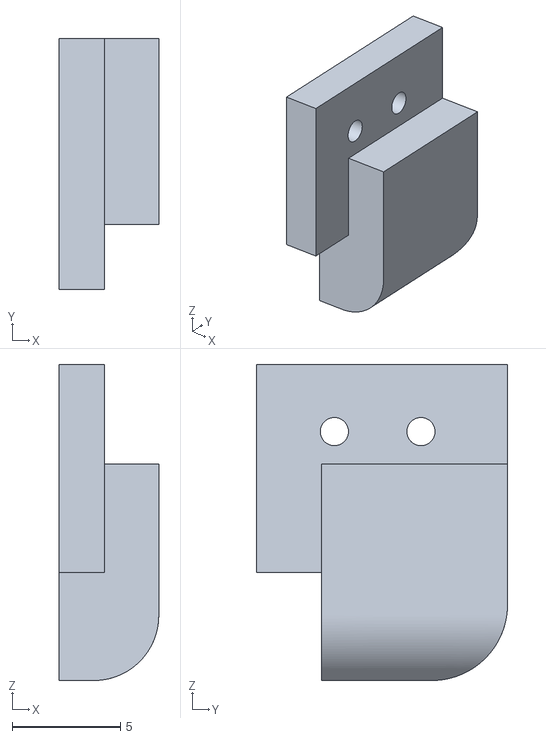
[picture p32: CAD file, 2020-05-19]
hardware/3D Files/4.shaft_limiter.stl
4.60 x 11.6 x 14.6

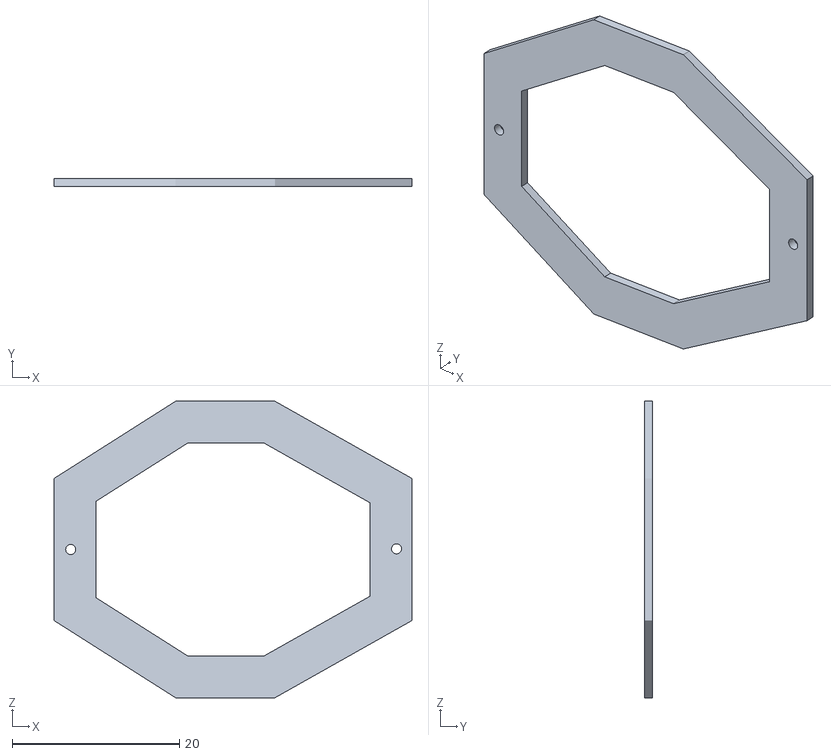
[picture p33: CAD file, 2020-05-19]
hardware/3D Files/3.Lock_OLED.stl
42.8 x 1.00 x 35.5

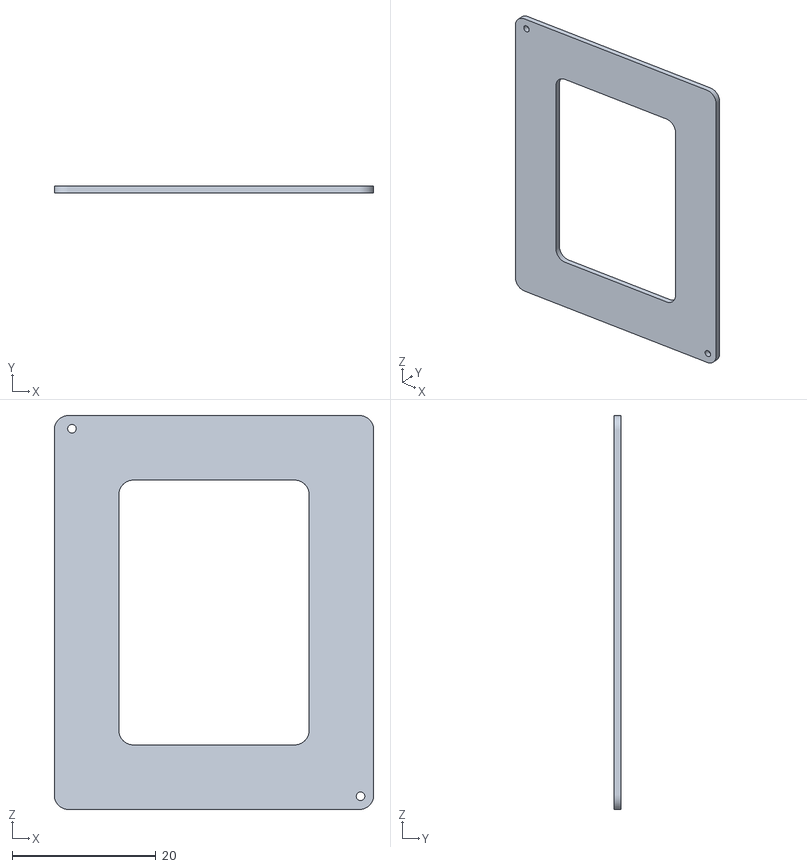
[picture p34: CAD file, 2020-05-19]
hardware/3D Files/3.Lock_Antena.stl
44.5 x 1.00 x 54.9

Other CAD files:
hardware/3D Files/Card Scanner Box v11.f3d

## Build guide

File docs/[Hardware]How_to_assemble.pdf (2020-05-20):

### CHƯƠNG 6: CÁCH THỨC LẮP ĐẶT VÀ VẬN HÀNH

### 6.1. Trình tự sắp xếp và hành linh kiện trên PCB

Do mạch được thiết kế theo dạng chồng tầng và các linh kiện được bố trí trên cả 2 mặt

của PCB nhằm tối ưu diện tích dẫn đến quy trình sắp xếp và hàn linh kiện lên PCB có phần

phức tạp.
- Module OLED 1.3 inch được hàn sẵn rào đực 4 chân thẳng nên không thể lắp ráp vào

hộp được. Đầu tiên cần hút thiếc rào cũ ra và thay thế bằng rào đực chân cong (cong

hướng vào trong, phía không có màn).
- Module mạch tăng áp cần hút thiếc đầu USB. Đối với mạch này sau khi được hút thiếc

thì chỉ có 2 chân ngoài cùng trong 4 chân là có kết nối với nguồn, 2 chân phía trong

không kết do không có chức năng truyền data. Tiếp đến hàn rào đực chân thẳng vào

4 pin: IN+ IN- OUT+ OUT- của mạch. Thực hiện tương tự với mạch sạc pin. Lưu ý, hai module này khoảng cách chân linh kiện không theo chuẩn 0.1inch nên ta không

thể sử dụng trực tiếp rào đực, cần cắt rào và cố định bằng keo trước khi hàn.

- Tiếp đến hút thiếc hai module RTC DS3231 và module đọc thẻ SD. Lưu ý, đối với

hai module này, không hàn rào mới vào. Cách thức lắp đặt sẽ khác với các linh kiện

khác vì được đặt ở vị trí có linh kiện ở mặt đối diện của PCB.

- Công tắc nguồn cho mạch được thiết kế hàn cố định trên PCB với mục đích cố định

1 góc của PCB khi lắp đặt vào khung chữ nhật trên hộp. Vì thế, cần được hàn nối dài

chân ngoài cùng trước khi tiến hành lắp ráp.

- Nút điều khiển 4 trạng thái là linh kiện dán nên cần ra chân để liên kết với mạch được

chắc chắn.

- Tiếp đến tiến hành hàn nút nhấn và các linh kiện liên kết:

+ 1x Công tắc nguồn

+ 1x Công tắc 4 trạng thái

+ 1x jack cắm cái 4 pin

+ 3x jack cắm cái 2 pin

+ 2x rào cái 15 pin
+ 2x rào đực 6 (kèm 2 lớp đế nhựa để căn khoảng cách từ module đến PCB)

+ 1x jack cắm đực 2 pin cho dây dẫn nguồn pin Lipo

- Thu ngắn dây bus 2 cho mạch đo pin và dây bus 4 cho mạch OLED. Lưu ý: hiện có

hai dòng màn hình OLED 1.3 inch trên thị trường. Hai dòng này có cấu trúc bên ngoài

gần như giống nhau nhưng kích thước kỹ thuật các bộ phận có sai khác một chút. Đặc

biệt là sơ đồ ra chân của hai dòng màn hình này khác nhau nên khi sử dụng nên kiểm

tra chân và đảo dây bus cho chính xác.
- Cụ thể, dòng thứ nhất (mẫu cũ) có kích thước các cạnh và khoảng cách lỗ nhỏ hơn 0.1

đến 0.2mm, khoảng cách từ màn hình đến module nhỏ hơn 0.2 đến 0.3mm so với dòng

màn hình thứ hai (mẫu mới). Sơ đồ chân như sau:

VCC GND SCL SDA (Mẫu cũ)

GND VCC SCL SDA (Mẫu mới)

- Chân VCC và GND của hai mẫu bị đảo với nhau nên màn hình dạng mẫu cũ có thể

kết nối bus 4 đến PCB theo đúng sơ đồ chân như bình thường. Còn với trường hợp

mẫu mới, dây bus ở hai chân đó cần được tách ra khỏi đầu cắm (phía kết nối vào

OLED) và đổi vị trí cho nhau, sau đó găm lại vào đầu cắm và sử dụng bình thường.

- Tiếp đến hàn các module vào mạch:

+ Module tăng áp

+ Module sạc pin Lipo 4.2V
Lưu ý: module này có hai dòng sản phẩm type C và micro USB nên tùy vào đối tượng

sử dụng mà chọn hàn loại nào vào mạch. (Sau khi hàn hai module nguồn vào mạch, cần cắt

ngắn chân và dán cách điện để tránh va chạm với các linh kiện khác, tiếp đến cắm pin Lipo

vào và tiến hành đo test nguồn).

+ Module đọc thẻ RDM6300

+ Module RTC DS3231

+ Module SD card
Lưu ý: các linh kiện bên dưới hai module RTC và SD card cần được cắt ngắn chân và

dán cách điện trước. Hai module này cũng cần được chêm bằng một mãu foam phía không

rào để tăng tính vững chắc. Cụ thể module RTC chêm foam 5mm, module SD card chêm

foam 3mm.

- Sau khi hàn hoàn tất Hình 6.1 có thể nạp cho ESP và cắm vào rào, hoàn tất PCB và

tiến hành chạy test.

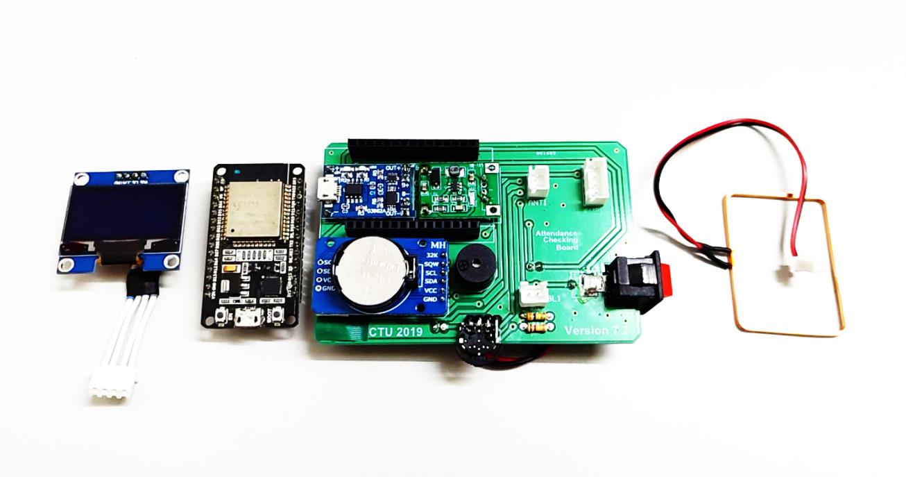
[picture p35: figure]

Hình 6. 1 Các thành phần mạch đã được chuẩn bị hoàn tất

### 6.2. Trình tự lắp ráp hộp mạch

- Đầu tiên, sau khi có đủ 4 bộ phận in 3D, 3 bộ phận mica 1.2mm và 1 bộ phận mica

3mm. Ta tiến hành sơn (2 – 3 lớp mỏng) các bộ phận mica và phần nắp hộp Hình 6.2.

Phần nắp cần được phun sơn trước khi được dán với mica ốp nắp do bản in 3D không

hoàn toàn mịn và các lớp in cạnh nhau ở một vài khu vực mỏng có thể sẽ có khoảng

hở dẫn đến khi dán bằng keo siêu dính làm bong tróc phần sơn dưới mặt mica ốp.

- Tiếp theo dán mica ốp vào mặt trên nắp hộp Hình 6.3 bằng keo siêu dính (supper glue)

lưu ý, không nên sử dụng keo dán ống PVC hoặc keo 502 do các sản phẩm này có thể

làm chảy và bong tróc lớp sơn vừa phun.
- Đặt module đo pin vào nắp hộp và cố định bằng vít M1.4x3.
- Đặt OLED và mica khóa vào nắp hộp và cố định bằng vít M1.4x3.
- Đặt anten vào rãnh, đặt tiếp mica khóa lên và cố định bằng vít M1.4x3.

- Sau khi cố định được các module trên nắp, cần dán cố định 1 phần dây anten gần rãnh

do bộ phận này nếu bị tác động nhiều có thể làm đứt dây đồng phía cuộn anten khi

đóng mở hộp nhiều lần.

- Tiếp đến đặt khóa mica 3mm vào hộp cùng với lò xo bút bi trong rãnh. Khóa lỏng lại

bằng phần in 3D đỡ mạch.

- Sau đó đặt pin lipo (đã kết nối PCB) vào rãnh pin (có dán keo 2 mặt với đáy hộp để

hạn chế va đập trong quá trình sử dụng).

- Đặt PCB vào hộp sao cho vị trí công tắc nguồn và nút nhấn 4 trạng thái vào rãnh.
- Khóa PCB bằng mica khóa 1.2mm, bắt vít M1.4x5 để cố định. (chỉ cần bắt 2 vít là

đủ). Lưu ý: Cần tháo rời module ESP32 để tiện cho việc bắt vít.

- Kết nối phần bản lề nắp hộp vào phần bản lề thân hộp.
- Đặt trục ∅2x100mm vào bản lề Hình 6.4.
- Khóa bản lền bằng bộ phận in 3D còn lại. Có thể dùng 2 vít M1x4 hoặc 2 vít M1.4x5

(tối ưu hơn do khi tháo lắp nhiều lần có thể dẫn đến lỏng lỗ vít khi chỉ sử dụng M1x4,

nhưng có thể bị dư một chút về phần chiều dài).

- Lắp đặt mica che các cổng kết nối vào rãnh.
- Cắm dây LCD, anten, module đo pin và tiến hành test.

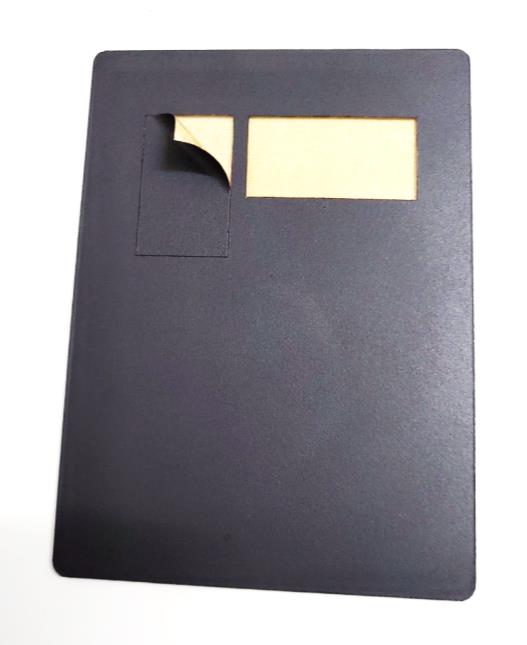
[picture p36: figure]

Hình 6. 2 Mặt mica ốp nắp đã được sơn

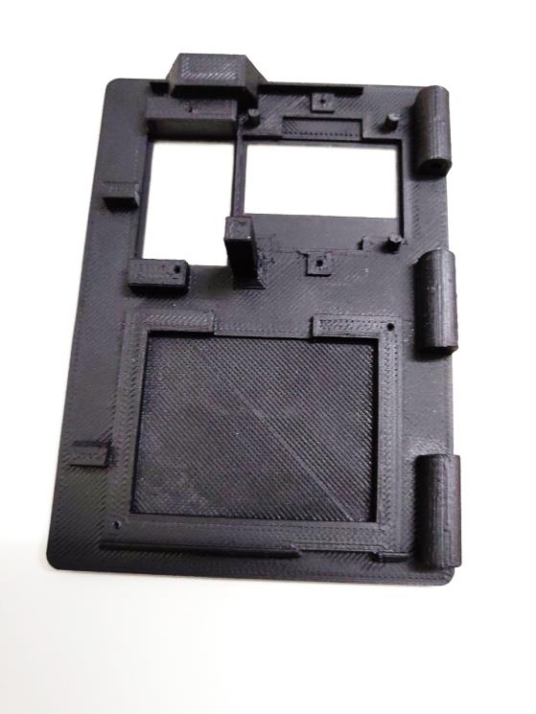
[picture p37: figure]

Hình 6. 3 Năp hộp sau khi dán tấm ốp

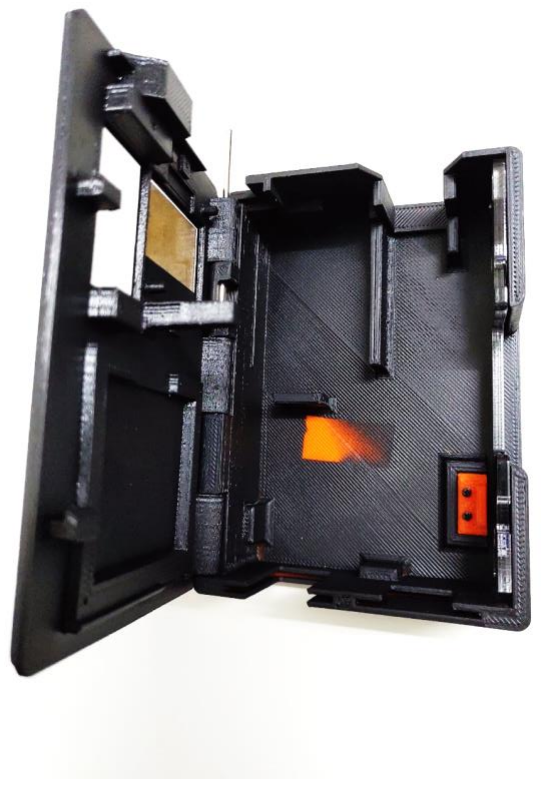
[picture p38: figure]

Hình 6. 4 Nắp và thân hộp sau khi đã được kết nối

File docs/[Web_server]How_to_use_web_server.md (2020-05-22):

# HƯỚNG DẪN SỬ DỤNG HỆ THỐNG (ĐÃ CÀI ĐẶT)

- Người dùng sẽ sử dụng trình duyệt web để truy cập vào trang đăng nhập của hệ thống (localhost:2020 hoặc tên miền global nếu đã cập nhật lên server).

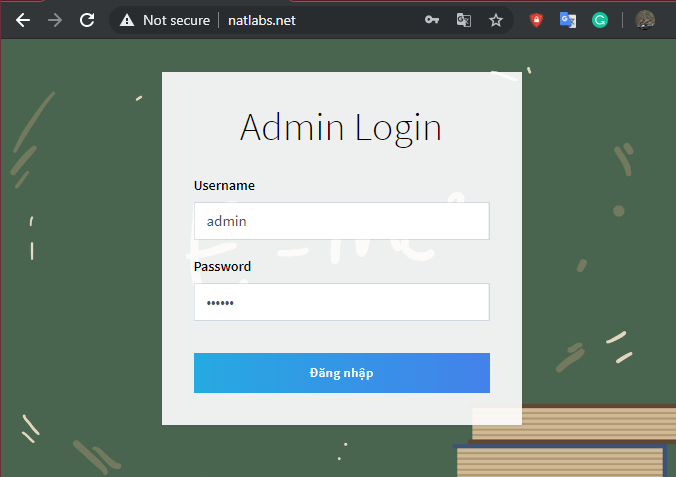
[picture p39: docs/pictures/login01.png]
Login menu 1
  

- Nhập tên đăng nhập và mật khẩu lần lượt vào ô Username và Password sau đó nhấp chuột chọn nút Đăng nhập (hoặc ấn Enter) để truy cập vào hệ thống.
- Trường hợp sai mật khẩu hoặc tên đăng nhập hệ thống sẽ thông báo như hình bên dưới. Ta tiến hành nhập lại đúng tài khoản sẽ đăng nhập được vào hệ thống.

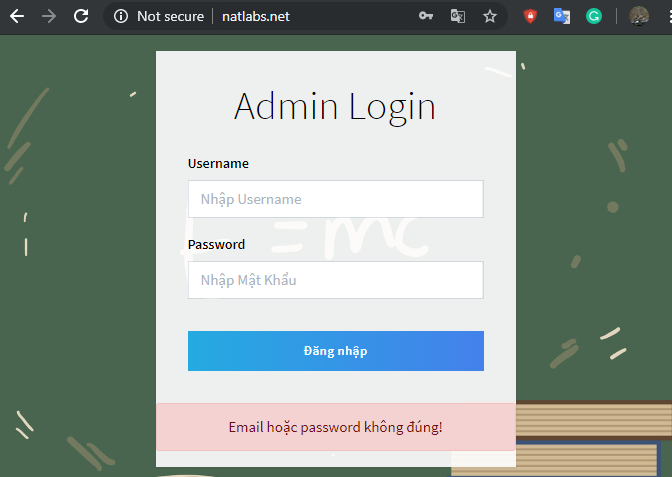
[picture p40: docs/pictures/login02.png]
Login menu 2
  

- Sau khi đăng nhập thành công, ta sẽ truy cập vào trang chủ như sau:

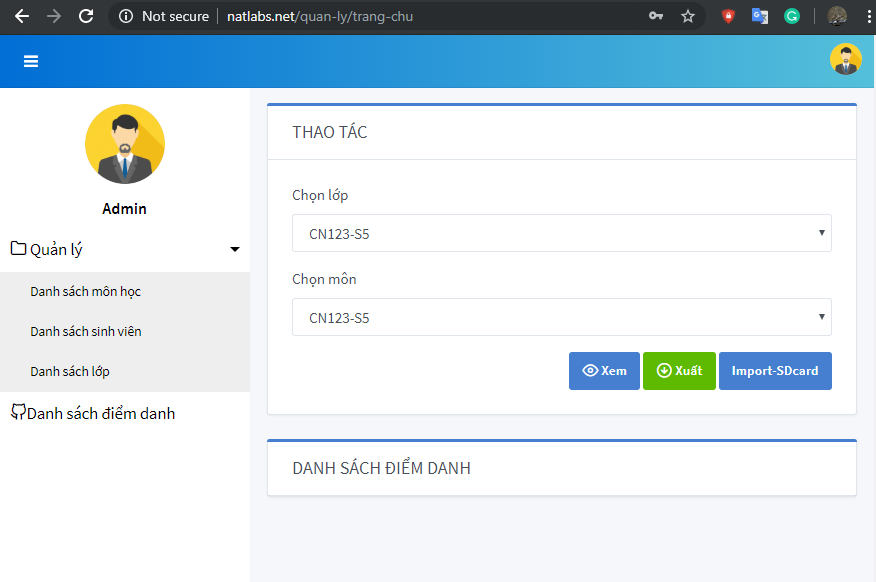
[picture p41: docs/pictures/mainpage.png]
mainpage
  

- Để tạo một lớp học phần ta tiến hành lần lượt theo các bước sau:
  - Nhấp chuột chọn mục “Danh sách môn học” trong danh mục Quản lý ở Tab bên trái.

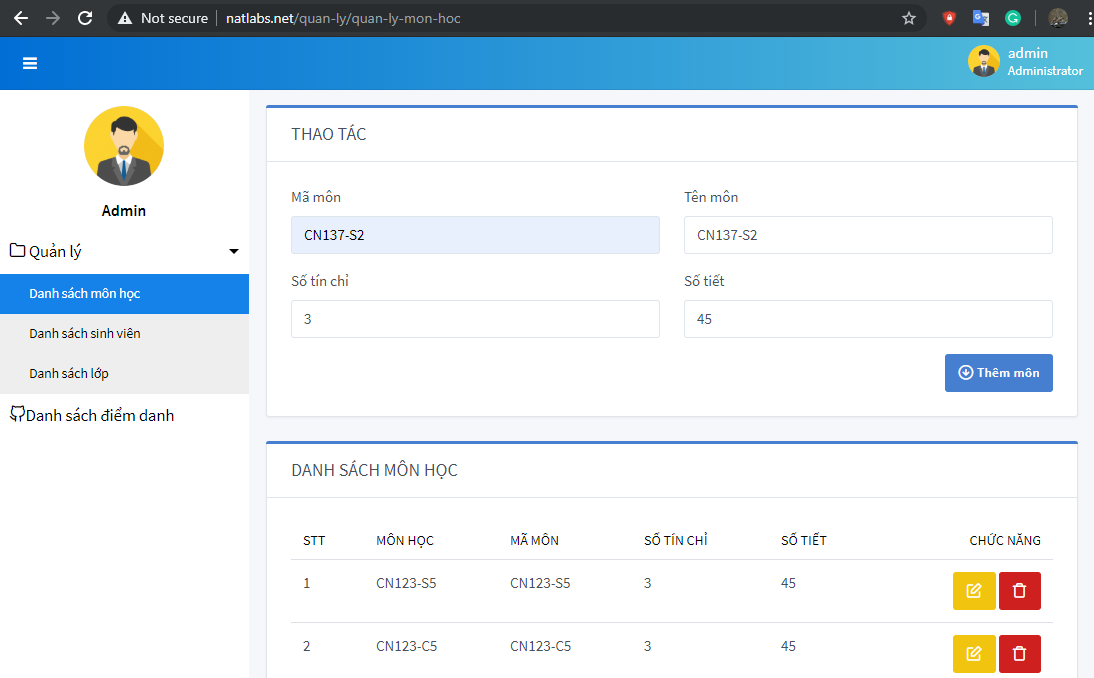
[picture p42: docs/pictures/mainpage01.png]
mainpage01
  

  - Nhập các thông tin của lớp học phần vào các ô tương ứng trong mục Thao tác. Ở đây đề xuất Mã môn học nhập theo nguyên tắc “Mã học phần – buổi học”. Lưu ý, thiết bị chỉ nhận Mã môn tối đa 8 ký tự. Cụ thể như “CN137-S2” là lớp học phần CN137 sáng thứ 2. (Tên môn nên đặt giống Mã môn để hiển thị ngắn gọn và đồng nhất ở mục Danh sách điểm danh). Số tín chỉ và Số tiết không được để trống nhưng không ảnh hưởng đến hệ thống.
  - Sau khi nhập đủ thông tin lớp học phần, nhấp chọn nút Thêm môn để kết thúc thao tác tạo lớp. Lớp vừa tạo sẽ xuất hiện trong mục Danh sách môn học bên dưới.
- Nhấp chọn danh mục Danh sách lớp trong Tab bên trái để mở giao diện danh sách lớp. Tiến hành nhập Mã lớp và Tên lớp vào 2 ô tương ứng trong khung Thao tác. Mã lớp ở đây phải trùng khớp với Mã môn đã tạo trong Danh sách môn học để liên kết dữ liệu 2 bảng. Xong thao tác nhập liệu ta nhấp chuột chọn nút Thêm danh sách lớp để kết thúc thêm lớp vào cơ sở dữ liệu.

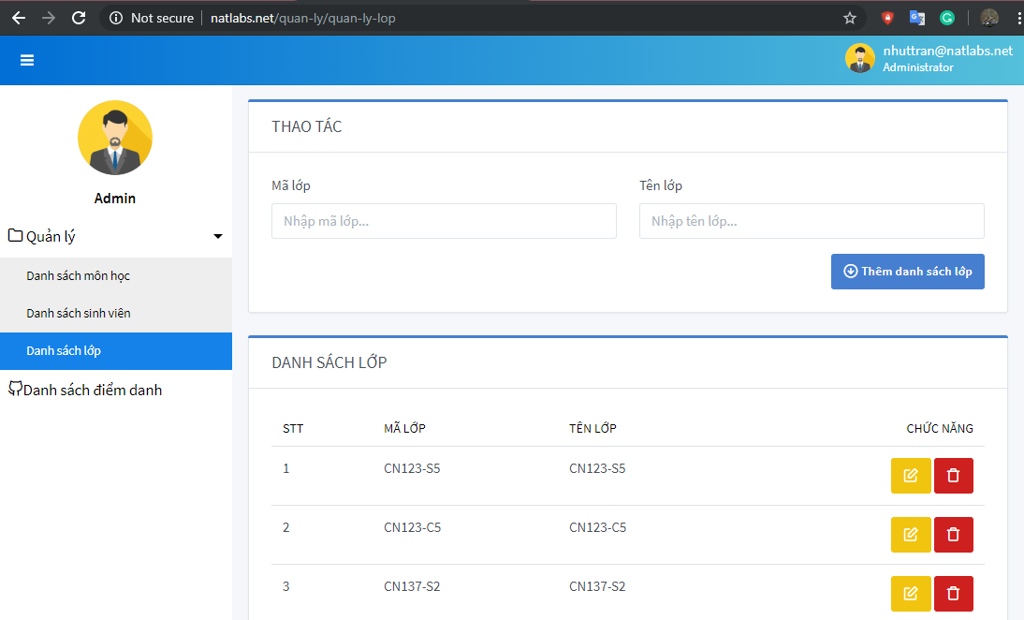
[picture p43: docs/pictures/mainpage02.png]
mainpage02
  

- Ta nhấp chọn danh mục Danh sách sinh viên trong Tab bên trái để mở giao diện quản lý sinh viên. Trong danh mục Danh sách sinh viên sẽ có 3 mục chính là Nhập sinh viên thủ công, Nhập dữ liệu từ Excel và Danh sách sinh viên.
- Để nhập sinh viên thủ công ta nhập lần lượt mã số sinh viên và tên sinh viên vào ô tương ứng. Chọn Giới tính và Lớp bằng cách nhấp chuột vào icon mũi tên bên phải mỗi trường tương ứng. Sau đó nhấp nút Thêm sinh viên.

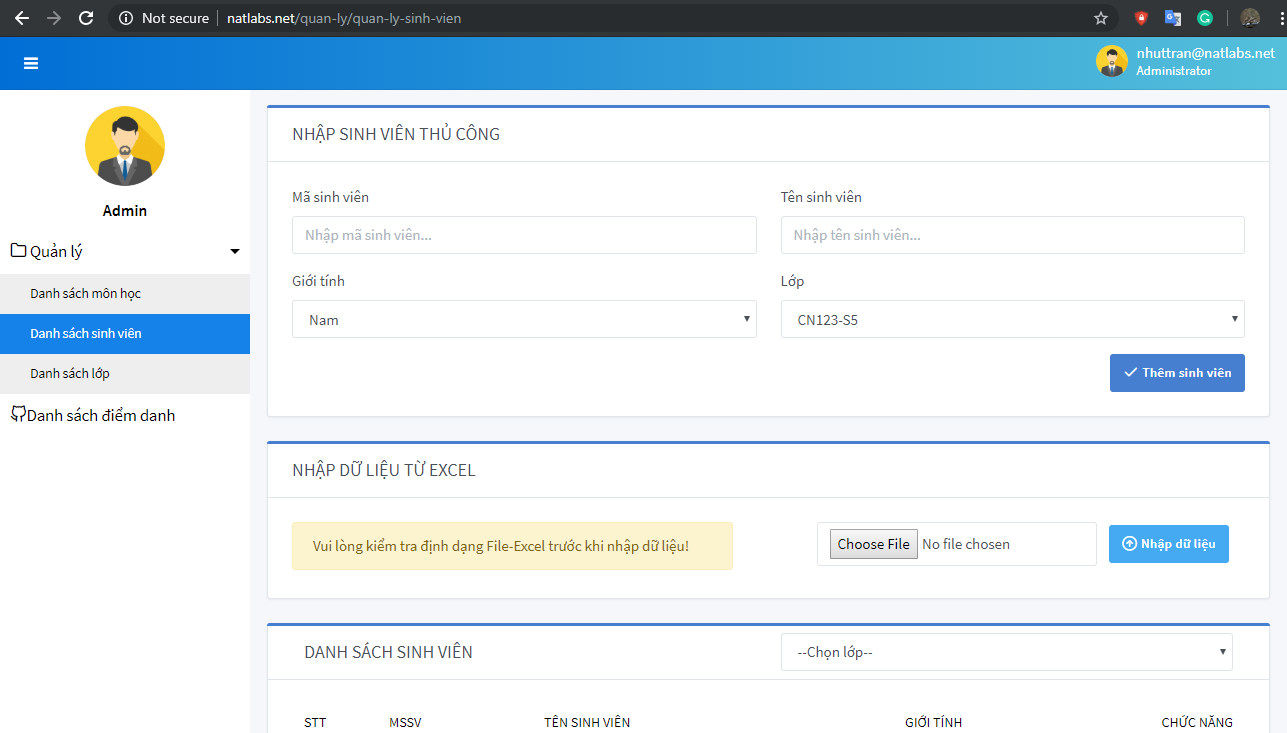
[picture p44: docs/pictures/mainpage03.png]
mainpage03
  

- Để nhập danh sách sinh viên từ File Excel, ta tạo dữ liệu Excel theo định dạng như hình dưới đây:

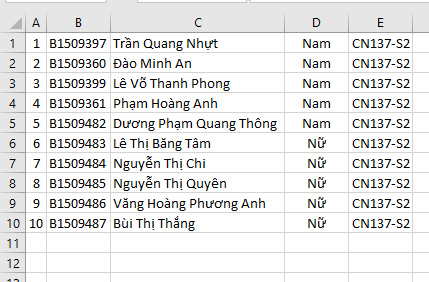
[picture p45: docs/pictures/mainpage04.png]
mainpage04
  

- File excel phải được định dạng gồm 5 cột. Cột A là số thứ tự, Cột B chứa Mã số sinh viên, Cột C chứ tên đầy đủ của sinh viên (có dấu hoặc không dấu – có thể chứa ký tự trống ở cuối nhưng không khuyến khích), Cột D là giới tính (Nam hoặc Nữ), Cột E chưa Mã lớp để liên kết với danh sách sinh viên tương ứng. File Excel có thể được lưu dưới tên bất kì.
- Nhấp chọn nút Choose File trong mục Nhập dữ liệu từ excel, trỏ tới đường dẫn chứa file excel trên máy tính và nhấn Open. Sau đó nhấp chọn nút Nhập dữ liệu. Khi nhập dữ liệu thành công ta có thể xem danh sách sinh viên ở mục Danh sách sinh viên bên dưới.
- Để xem danh sách sinh viên đã điểm danh, ta nhấp chọn danh mục Danh sách điểm danh ở Tab bên trái.

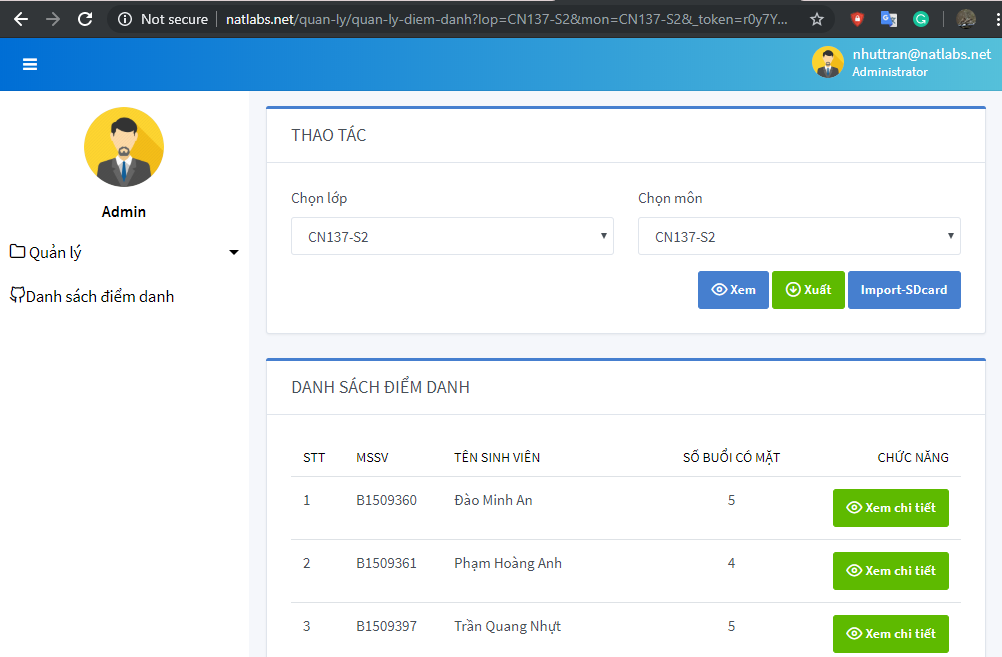
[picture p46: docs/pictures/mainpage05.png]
mainpage05
  

- Ta chọn lớp và môn tương ứng xong chọn nút Xem để xem danh sách đã điểm danh ở mục Danh sách điểm danh bên dưới. Hoặc nhấp chọn nút Xuất để tải về file excel chứa dữ liệu điểm danh tương ứng của lớp học phần đó.
- Muốn xem chi tiết điểm danh của một sinh viên, ta nhấp chọn nút Xem chi tiết ứng với mỗi tên sinh viên. Kết quả như hình bên dưới:

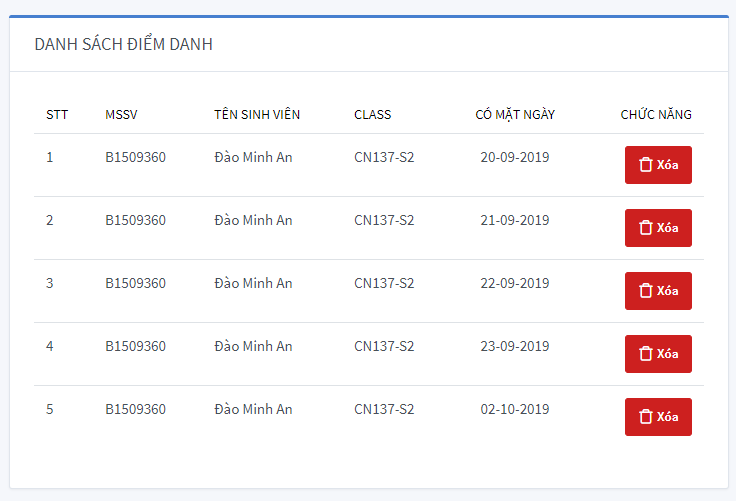
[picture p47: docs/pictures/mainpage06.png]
mainpage06
  

- Dữ liệu chi tiết chỉ cho phép xóa chứ không được chỉnh sửa thông tin. Ngày điểm danh được sinh ra từ thiết bị khi sinh viên quét thẻ điểm danh.
- File excel chứa dữ liệu điểm danh khi tải về máy sẽ thể hiện như sau:

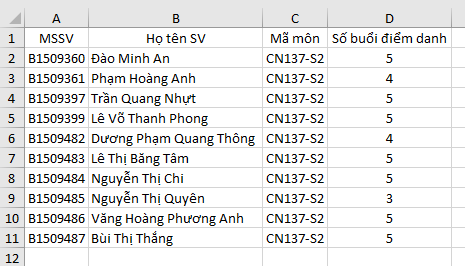
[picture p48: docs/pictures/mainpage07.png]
mainpage07


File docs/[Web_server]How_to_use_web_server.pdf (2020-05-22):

# HƯỚNG DẪN SỬ DỤNG HỆ THỐNG (ĐÃ CÀI ĐẶT)

Người dùng sẽ sử dụng trình duyệt web để truy cập vào trang đăng nhập của hệ thống (localhost:2020 hoặc tên miền global nếu đã cập nhật lên server).


Nhập tên đăng nhập và mật khẩu lần lượt vào ô Username và Password sau đó nhấp chuột chọn nút Đăng nhập (hoặc ấn Enter) để truy cập vào hệ thống.

Trường hợp sai mật khẩu hoặc tên đăng nhập hệ thống sẽ thông báo như hình bên dưới. Ta tiến hành nhập lại đúng tài khoản sẽ đăng nhập được vào hệ thống.

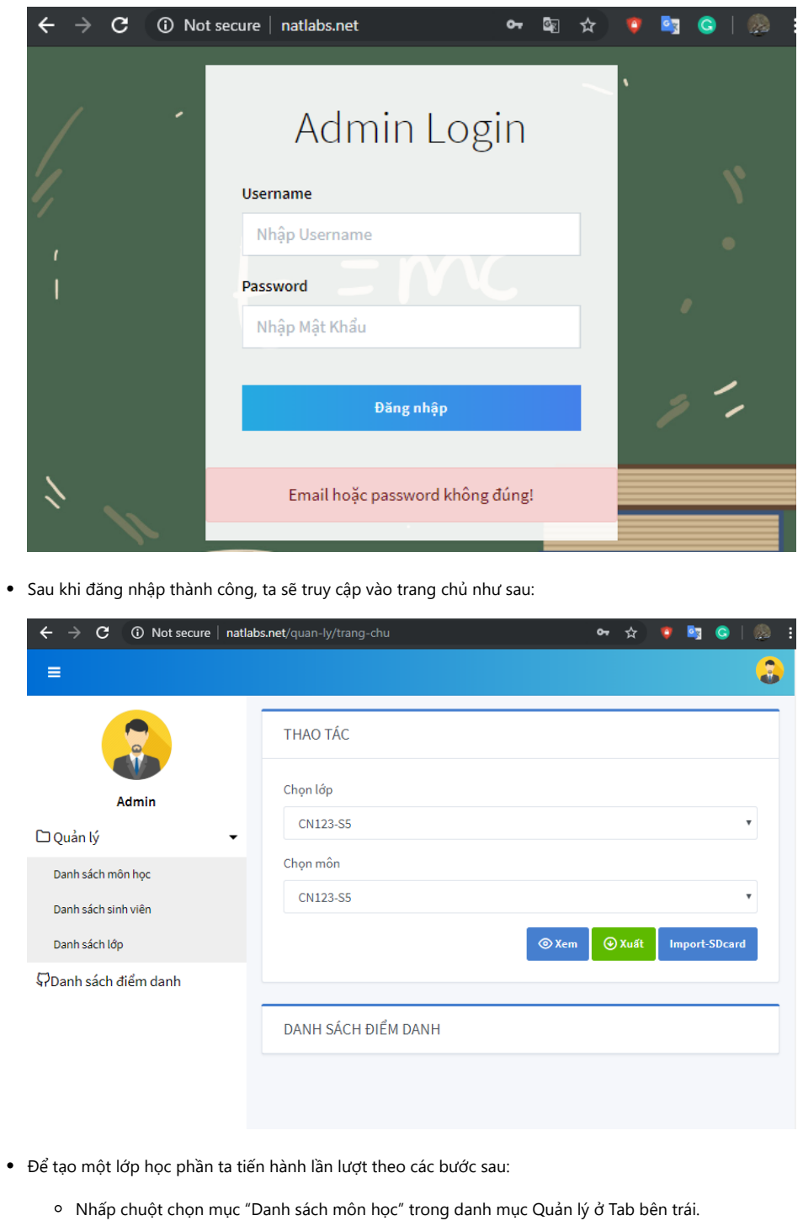
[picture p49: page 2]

Sau khi đăng nhập thành công, ta sẽ truy cập vào trang chủ như sau:

Để tạo một lớp học phần ta tiến hành lần lượt theo các bước sau:

Nhấp chuột chọn mục “Danh sách môn học” trong danh mục Quản lý ở Tab bên trái.


Nhập các thông tin của lớp học phần vào các ô tương ứng trong mục Thao tác. Ở đây đề xuất Mã môn học nhập theo nguyên tắc “Mã học phần – buổi học”. Lưu ý, thiết bị chỉ nhận Mã môn tối đa 8 ký tự. Cụ thể như “CN137-S2” là lớp học phần CN137 sáng thứ 2. (Tên môn nên đặt giống Mã môn để hiển thị ngắn gọn và đồng nhất ở mục Danh sách điểm danh). Số tín chỉ và Số tiết không được để trống nhưng không ảnh hưởng đến hệ thống.
Sau khi nhập đủ thông tin lớp học phần, nhấp chọn nút Thêm môn để kết thúc thao tác tạo lớp. Lớp vừa tạo sẽ xuất hiện trong mục Danh sách môn học bên dưới.

Nhấp chọn danh mục Danh sách lớp trong Tab bên trái để mở giao diện danh sách lớp. Tiến hành nhập Mã lớp và Tên lớp vào 2 ô tương ứng trong khung Thao tác. Mã lớp ở đây phải trùng khớp với Mã môn đã tạo trong Danh sách môn học để liên kết dữ liệu 2 bảng. Xong thao tác nhập liệu ta nhấp chuột chọn nút Thêm danh sách lớp để kết thúc thêm lớp vào cơ sở dữ liệu.

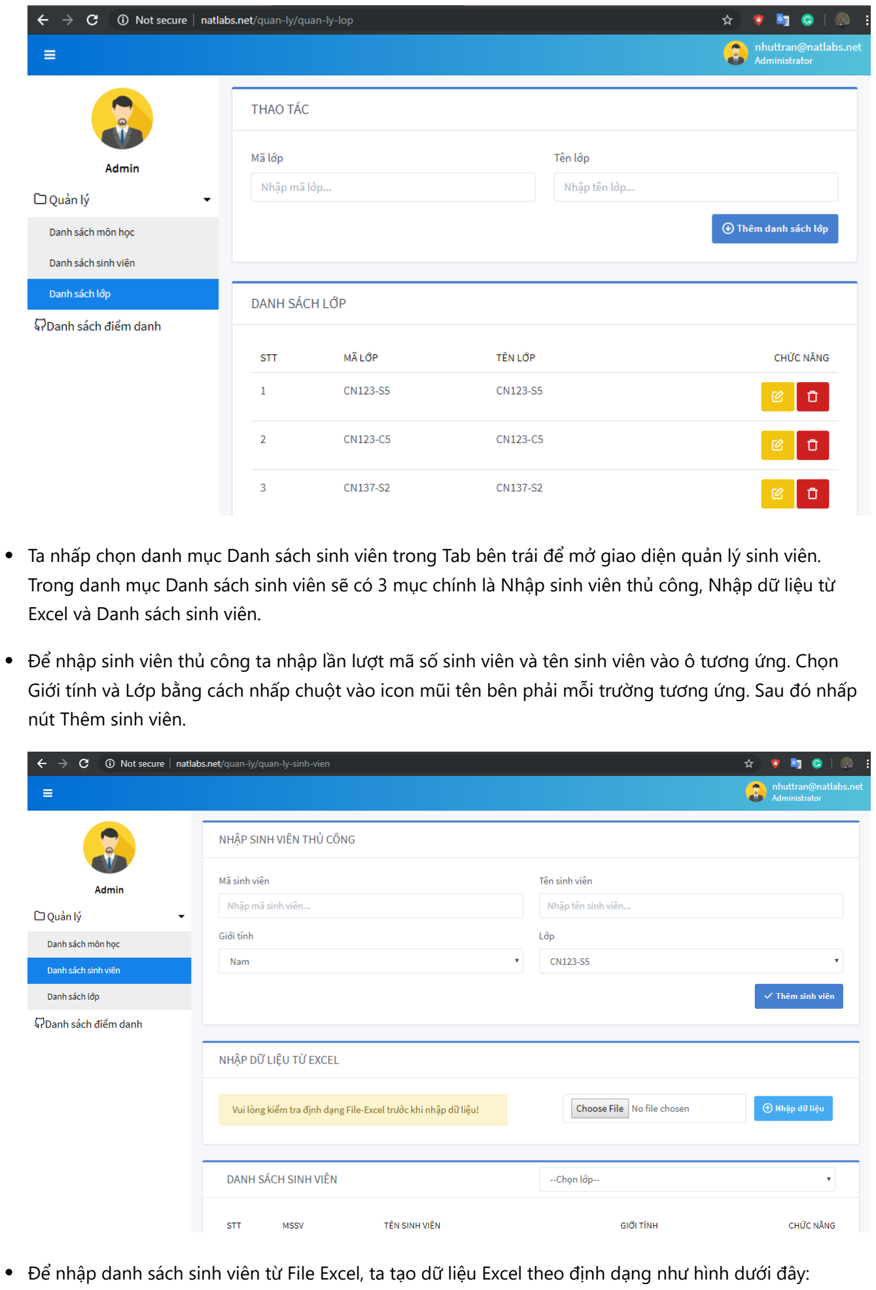
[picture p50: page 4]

Ta nhấp chọn danh mục Danh sách sinh viên trong Tab bên trái để mở giao diện quản lý sinh viên. Trong danh mục Danh sách sinh viên sẽ có 3 mục chính là Nhập sinh viên thủ công, Nhập dữ liệu từ Excel và Danh sách sinh viên.

Để nhập sinh viên thủ công ta nhập lần lượt mã số sinh viên và tên sinh viên vào ô tương ứng. Chọn Giới tính và Lớp bằng cách nhấp chuột vào icon mũi tên bên phải mỗi trường tương ứng. Sau đó nhấp nút Thêm sinh viên.

Để nhập danh sách sinh viên từ File Excel, ta tạo dữ liệu Excel theo định dạng như hình dưới đây:

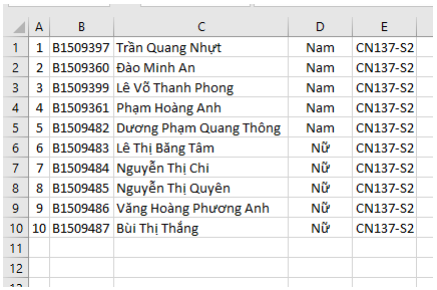
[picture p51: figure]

File excel phải được định dạng gồm 5 cột. Cột A là số thứ tự, Cột B chứa Mã số sinh viên, Cột C chứ tên đầy đủ của sinh viên (có dấu hoặc không dấu – có thể chứa ký tự trống ở cuối nhưng không khuyến khích), Cột D là giới tính (Nam hoặc Nữ), Cột E chưa Mã lớp để liên kết với danh sách sinh viên tương ứng. File Excel có thể được lưu dưới tên bất kì.

Nhấp chọn nút Choose File trong mục Nhập dữ liệu từ excel, trỏ tới đường dẫn chứa file excel trên máy tính và nhấn Open. Sau đó nhấp chọn nút Nhập dữ liệu. Khi nhập dữ liệu thành công ta có thể xem danh sách sinh viên ở mục Danh sách sinh viên bên dưới.

Để xem danh sách sinh viên đã điểm danh, ta nhấp chọn danh mục Danh sách điểm danh ở Tab bên trái.

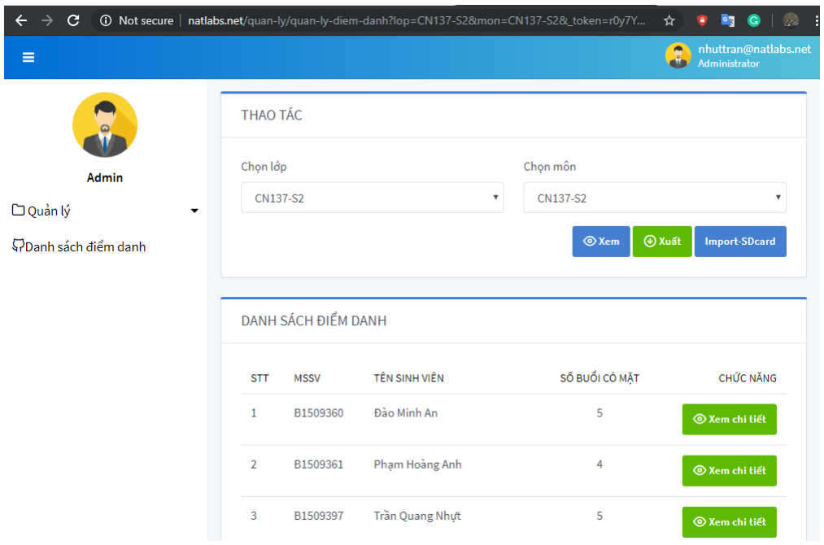
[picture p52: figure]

Ta chọn lớp và môn tương ứng xong chọn nút Xem để xem danh sách đã điểm danh ở mục Danh sách điểm danh bên dưới. Hoặc nhấp chọn nút Xuất để tải về file excel chứa dữ liệu điểm danh tương ứng

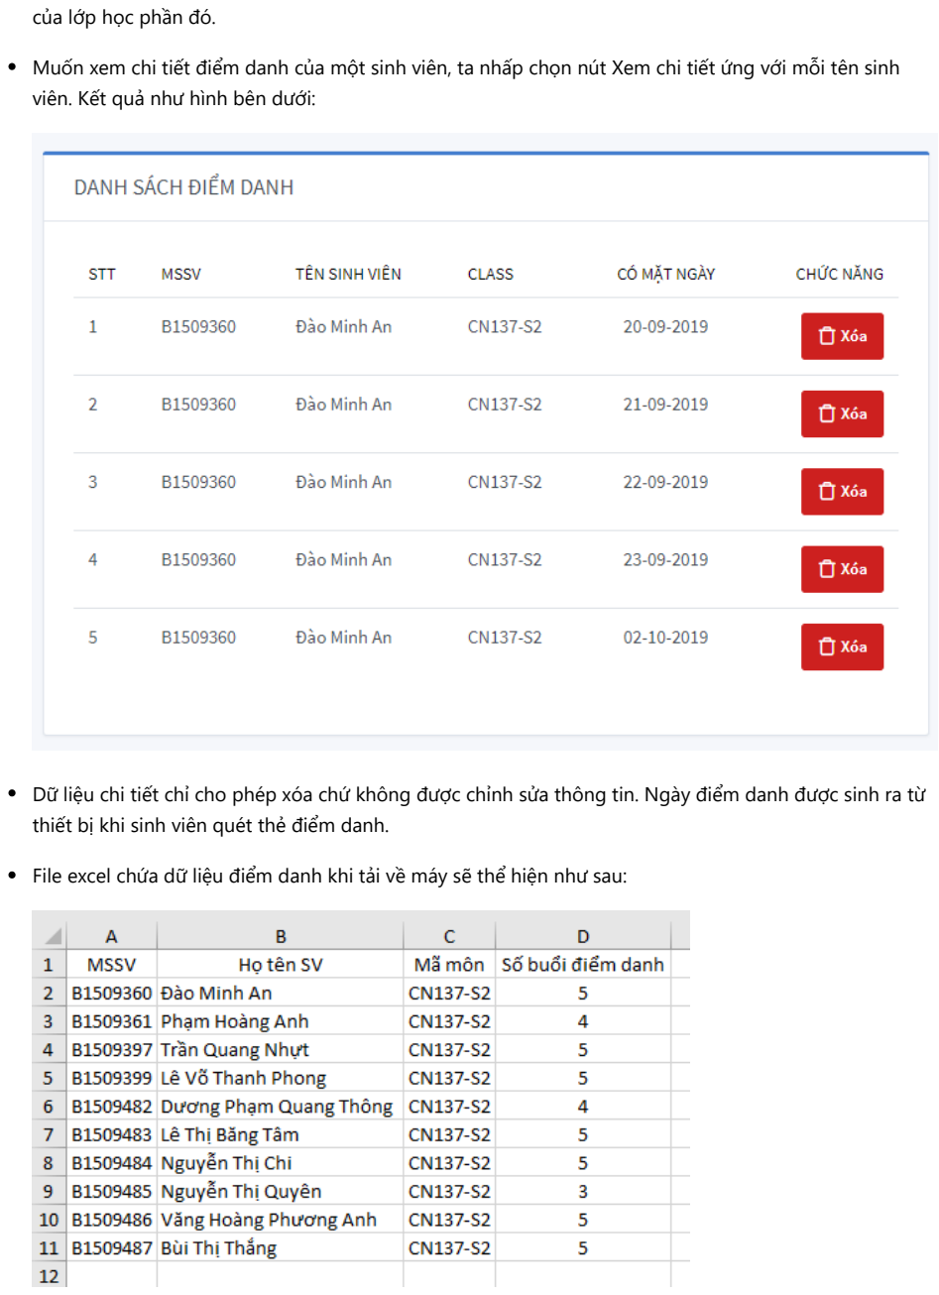
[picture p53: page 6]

của lớp học phần đó.

Muốn xem chi tiết điểm danh của một sinh viên, ta nhấp chọn nút Xem chi tiết ứng với mỗi tên sinh viên. Kết quả như hình bên dưới:

Dữ liệu chi tiết chỉ cho phép xóa chứ không được chỉnh sửa thông tin. Ngày điểm danh được sinh ra từ thiết bị khi sinh viên quét thẻ điểm danh.

File excel chứa dữ liệu điểm danh khi tải về máy sẽ thể hiện như sau:

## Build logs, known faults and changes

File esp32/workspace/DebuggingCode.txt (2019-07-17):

xtensa-esp32-elf-gdb ./build/CARD-SCANNER.elf -b 115200 -ex 'target remote COM5'

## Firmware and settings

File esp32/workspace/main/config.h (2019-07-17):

/*------------------------------------------------------------*-
  Configuration file
  (c) An Minh Dao 2019
  version 2.00 - 09/02/2019
---------------------------------------------------------------
 * Basic settings for type of:
 * - Microcontroller
 * - SSID reader
 * - Buzzer
 * - TFT Screen controller
 * - RTC module
 * - SD card module
 * - CORE0
 * - MQTT WIFI CHANGEABLE
 * 
 * 
 * 
TASKS           STATE	PIORITY	STACK	NUM	CORE
IDLE1          	R	0	1012	7	1
IDLE0          	R	0	1020	6	0
TASKS_MONITOR  	R	0	456	14	-1
C1_Combined    	R	0	8176	13	1
C0_Combined    	B	0	3136	12	0
tiT            	B	18	2516	18	-1
Tmr Svc        	B	1	1628	8	0
network_event  	B	19	3620	16	-1
ipc0           	B	24	604	2	0
esp_timer      	B	22	3460	1	0
wifi           	B	23	1660	19	0
ipc1           	B	24	548	3	1
eventTask      	B	20	1960	17	0

TASKS           ABSOLUTE TIME	PERCENT TIME
IDLE1          	12888982		32%
IDLE0          	17055260		42%
TASKS_MONITOR  	84355		<1%
C1_Combined    	6809296		17%
C0_Combined    	8381		<1%
tiT            	106474		<1%
Tmr Svc        	18070		<1%
ipc0           	2762		<1%
ipc1           	158082		<1%
esp_timer      	30745		<1%
wifi           	2679112		6%
eventTask      	1187		<1%
network_event  	446		<1%

 * 
 * 
 * 
--------------------------------------------------------------*
* ADVANCED SETTING:
 * - In components/arduino/libraries/wifi/src/WifiGeneric.cpp
 *   + xTaskCreatePinnedToCore(_network_event_task, "network_event", 4096, NULL, ESP_TASKD_EVENT_PRIO - 1, &_network_event_task_handle, tskNO_AFFINITY);
 *     => changed variable function from ARDUINO_RUNNING_CORE (core1) to tskNO_AFFINITY (either core is free)
 *   + if(event->event_id < 26) {log_d("Event: %d - %s", event->event_id, system_event_names[event->event_id]);}
 *     => add {} to the if command
 * - Turn on/off log:
 *    + Initial log: connect GPIO15 to GND
 *    + Bootloader log: make menuconfig --> Bootloader config --> Bootloader log verbosity --> No output
 *    + FreeRTOS, wifi, bluetooth log: make menuconfig --> Components config --> log output --> Default log verbosity --> No output
 * - Set panic action:
 *    make menuconfig --> Components config --> ESP32-specific --> Panic handler behavior
 * - Monitor which tasks running: vTaskList() (turn off when complete)
 *    make menuconfig --> Components config --> FreeRTOS --> Enable FreeRTOS trace facility
 *    make menuconfig --> Components config --> FreeRTOS --> Enable FreeRTOS stats formatting functions
 *    make menuconfig --> Components config --> FreeRTOS --> Enable display of xCoreID in vTaskList
 * - Monitor how much time tasks has been executed: vTaskGetRunTimeStats() (turn off when complete)
 *    make menuconfig --> Components config --> FreeRTOS --> Enable FreeRTOS to collect run time stats
 * - Make long filename in SD card:
 *    make menuconfig --> Components config --> FAT filesystem support --> Long filename support in heap
 *  --> Current setting: short filename (<=8 characters) - a 8.3 filename 
 *  --> in a 8.3 filename system, file and directory names are uppercase!
 *  readmore: https://en.m.wikipedia.org/wiki/8.3_filename
 * 
 * - Changed I2C default frequency in esp32-hal-i2c.c, 
 *   function i2cInit() from frequency = 100000L; to frequency = 400000L;
 * - PARTITION TABLE EDITED! original csv file located at: <ESPIDF>/components/partition_table/
 * --> make menuconfig --> Partition Table --> Custom partition table CSV
 * ---> open partition.csv in <workspace>/partition.csv
 * ---> change factory memory to 2Mb
 * 
 *  - Already TURN OFF Task watchdog for Idle tasks of core 1 and core 0
 * --> make menuconfig --> Components config --> ESP32-specific --> turn off Watch CPU0/1 Idle task
 * NOTE ABOUT NAME OF FILES:
 * C0  - module runs in core0 - combined task
 * C0I - module runs independently in a task in core1
 * C1  - module runs in core1 - combined task
 * C1I - module runs independently in a task in core1
 * N   - module runs in whichever core is free - combined task
 * NI  - module runs independently in a task in whichever core is free
 * 
 * 
 * ESP-IDF version: 3.2
 * Compiler version: 5.2.0
 * Arduino components version: newest
--------------------------------------------------------------*/
#ifndef _CONFIG_H
#define _CONFIG_H

/////////////////////////////////////////////////////////////////////////////////////////////////////////////////////
////////////////////////////////////MODE CONFIGS/////////////////////////////////////////////////////////////////////

//--------------------------------------------------------------
// USER DEFINE
// - SLASS OUT ANY OPTION THAT YOU DON'T WANT TO HAVE
//--------------------------------------------------------------
#define ESP32_DEBUG
#define WIFI_CHANGEABLE
#define SERIAL_OUTPUT
//#define TASKS_MONITOR //remember to change menuconfig when this is active
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

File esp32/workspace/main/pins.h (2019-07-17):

/*------------------------------------------------------------*-
  Pins assignment file
  (c) An Minh Dao 2019
  version 1.00 - 30/01/2019
---------------------------------------------------------------
 * Pin assigned for:
 * - SSID reader
 * - Buzzer
 * - TFT Screen
 * - RTC module
 * - SD card module
 * - CORE0
 * - MQTT WIFI CHANGEABLE
--------------------------------------------------------------*/
#ifndef _PINS_H
#define _PINS_H

//--------------------------------------------------------------
// CARD READER 125KHZ - RDM6300
//--------------------------------------------------------------
/*GPIO16 - RX2 to data pin of rf125khz*/ //USE A WHOLE UART PORT FOR DATA AQUISITION
#define RF_INTERRUPT_PIN  27
#define BUZZER_PIN        12      

//--------------------------------------------------------------
// OLED SCREEN - I2C 
//--------------------------------------------------------------
// - Changed I2C default frequency in esp32-hal-i2c.c, 
//  function i2cInit() from frequency = 100000L; to frequency = 400000L;
#define I2C_SDA_PIN  21 //automatically assigned
#define I2C_SCL_PIN  22 //automatically assigned
//--------------------------------------------------------------
// RTC MODULE - AT24C32 RAM IC - I2C
//--------------------------------------------------------------
// - Changed I2C default frequency in esp32-hal-i2c.c, 
//  function i2cInit() from frequency = 100000L; to frequency = 400000L;
#define I2C_SDA_PIN  21 //automatically assigned
#define I2C_SCL_PIN  22 //automatically assigned
//--------------------------------------------------------------
// SD CARD - SPI
//--------------------------------------------------------------
#define SPI_CS_PIN    5  //automatically assigned
#define SPI_CLK_PIN   18 //automatically assigned
#define SPI_MOSI_PIN  23 //automatically assigned
#define SPI_MISO_PIN  19 //automatically assigned
//--------------------------------------------------------------
// SWITCH
//--------------------------------------------------------------
#define SW_UP_PIN    32 //automatically assigned
#define SW_MID_PIN   4  //automatically assigned
#define SW_DOW_PIN   33 //automatically assigned
//--------------------------------------------------------------
// CORE0
//--------------------------------------------------------------
// No pin needed

//--------------------------------------------------------------
// CORE1
//--------------------------------------------------------------
// No pin needed

//--------------------------------------------------------------
// WIFI STATION CHANGEABLE
//--------------------------------------------------------------
// No pin needed

#endif //_PINS_H

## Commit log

2019-07-17 version 16 first commit
    [default.csv, default_16MB.csv, default_8MB.csv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]
2019-10-05 latest stable release. fix clock and continue addclass mode
    [C1_OLED.cpp, C1_RTC_DS3231.cpp, C1_Scenarios.cpp]
2020-05-19 refactor project tree, update server code and embedded code
    [default.csv, default_16MB.csv, default_8MB.csv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]
2020-05-19 update hardware components and change embedded code directory
    [1.Top.stl, 2.Bottom.stl, 2.Bottom_Support_PCB.stl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]
2020-05-19 update arduino submodule to tag 1.0.2
2020-05-20 update instruction on hardware assemling and device using
2020-05-20 update pcb pictures
2020-05-28 update examples and fix bugs
    [Class-import-example.xlsx, Export-example.xlsx]

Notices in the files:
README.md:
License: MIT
